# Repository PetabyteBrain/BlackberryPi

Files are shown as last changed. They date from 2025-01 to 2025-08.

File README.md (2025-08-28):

<!-- Improved compatibility of back to top link: See: https://github.com/othneildrew/Best-README-Template/pull/73 -->

<!--
*** Thanks for checking out the Best-README-Template. If you have a suggestion
*** that would make this better, please fork the repo and create a pull request
*** or simply open an issue with the tag "enhancement".
*** Don't forget to give the project a star!
*** Thanks again! Now go create something AMAZING! :D
-->

<!-- PROJECT SHIELDS -->
<!--
*** I'm using markdown "reference style" links for readability.
*** Reference links are enclosed in brackets [ ] instead of parentheses ( ).
*** See the bottom of this document for the declaration of the reference variables
*** for contributors-url, forks-url, etc. This is an optional, concise syntax you may use.
*** https://www.markdownguide.org/basic-syntax/#reference-style-links
-->
[][contributors-url]
[][forks-url]
[][stars-url]
[][issues-url]
[][license-url]
[][linkedin-url]

<!-- PROJECT LOGO -->
<br />
<div align="center">
  <a href="https://github.com/PetabyteBrain/BlackberryPi">
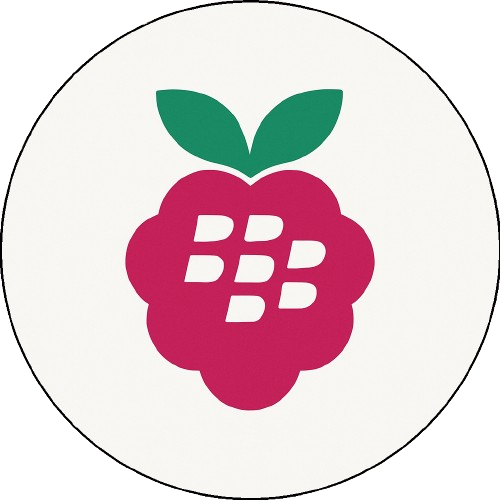
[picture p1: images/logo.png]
    
  </a>

<h3 align="center">Blackberry Pi</h3>

  <p align="center">
    The "BlackBerry Pi" project aims to transform a classic BlackBerry phone by integrating a Raspberry Pi as its core, creating a modern, customizable device with a retro design.
    <br />
    <a href="https://github.com/PetabyteBrain/BlackberryPi"><strong>Explore the docs »</strong></a>
    <br />
    <br />
    <a href="https://github.com/PetabyteBrain/BlackberryPi">View Demo</a>
    ·
    <a href="https://github.com/PetabyteBrain/BlackberryPi/issues/new?labels=bug&template=bug-report---.md">Report Bug</a>
    ·
    <a href="https://github.com/PetabyteBrain/BlackberryPi/issues/new?labels=enhancement&template=feature-request---.md">Request Feature</a>
  </p>
</div>

<!-- TABLE OF CONTENTS -->
<details>
  <summary>Table of Contents</summary>
  <ol>
    <li>
      <a href="#about-the-project">About The Project</a>
      <ul>
        <li><a href="#built-with">Built With</a></li>
      </ul>
    </li>
    <li>
      <a href="#getting-started">Getting Started</a>
      <ul>
        <li><a href="#prerequisites">Prerequisites</a></li>
        <li><a href="#installation">Installation</a></li>
        <li><a href="#additional-stuff">Additional stuff</a></li>
      </ul>
    </li>
    <li><a href="#build-example">Build example</a></li>
    <li><a href="#roadmap">Roadmap</a></li>
    <li><a href="#BOM (Bill of Materials)">BOM (Bill of Materials)</a></li>
    <li><a href="#contributing">Contributing</a></li>
    <li><a href="#license">License</a></li>
    <li><a href="#contact">Contact</a></li>
    <li><a href="#acknowledgments">Acknowledgments</a></li>
    <li><a href="#scripts">Scripts</a></li>
    <li><a href="#3d-plans">3D Plans</a></li>
  </ol>
</details>

<!-- ABOUT THE PROJECT -->
## About The Project

<div align="center">
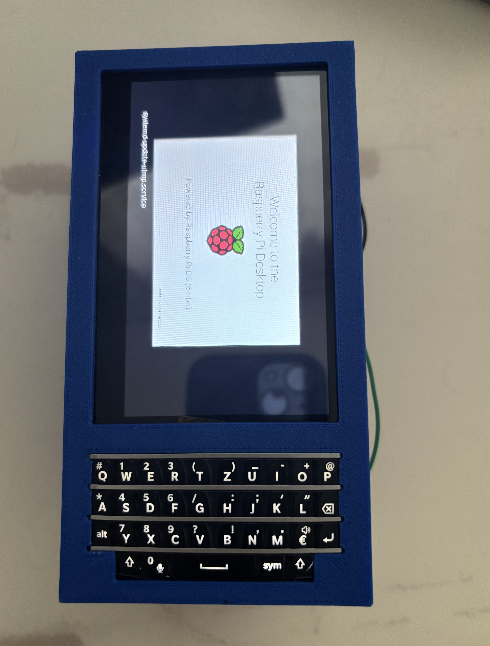
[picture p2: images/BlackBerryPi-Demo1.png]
Blackberry Pi
  
</div>

This project is all about bringing the iconic BlackBerry style back to life but with a twist. Instead of using outdated hardware, we’re giving it a modern upgrade by building it around a Raspberry Pi. The idea is to create something that feels unique and different from the sea of touchscreens we see today while keeping it open, customizable, and fun to work with. It’s a mix of nostalgia and innovation for people who want something truly their own.
This project is under development at the moment and is a working process. Updates in this repository are to be expected.

<p align="right">(<a href="#readme-top">back to top</a>)</p>

### Built With

* [][Raspberry-url]
* [][Arduino-url]

...

<p align="right">(<a href="#readme-top">back to top</a>)</p>

<!-- GETTING STARTED -->
## Getting Started

For getting a good start it is best if you buy or install the following prerequisites and installations.  Additionally for the customization it is easiest if you have access to a 3D-printer.

### Prerequisites

<div align="center">
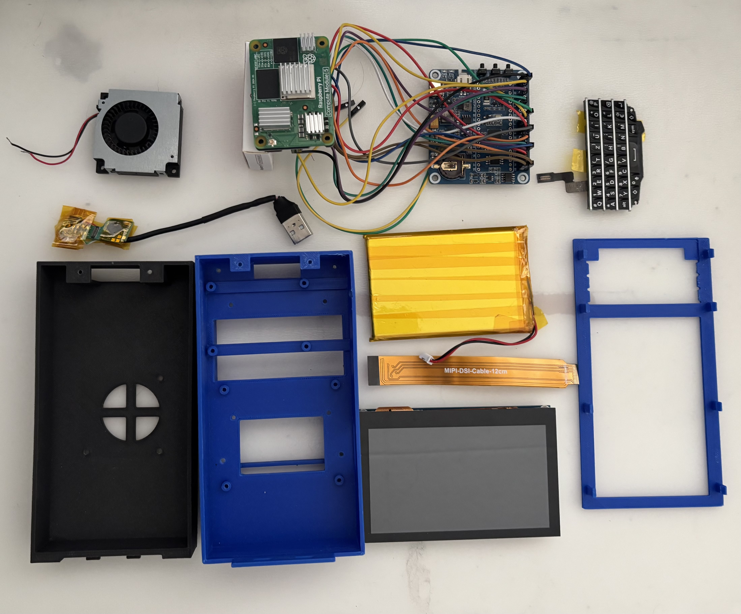
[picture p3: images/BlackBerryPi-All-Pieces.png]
Blackberry Pi
  
</div>

#### Hardware:
- Raspberry Pi Compute Module 5
- 4.3inch DSI LCD [from Waveshare]
- Nano Base Board A for CM5 [from Waveshare]
- Lipo Batterie 5000mAH 3.7V
- Power Management Hat (B) [from Waveshare]
- Keyboard from an old Blackberry Phone [from e.g. Ricardo]
- DC Brushless Fan DC12V - 0.18A Model: JD4512M12 [from e.g. eBay or a 3D-printer]

#### Software:
- On the Power Management Hat and on the Keyboard, flash these <a href="#scripts">scripts</a> for correct functionality.

### Installation:

- Raspberry Pi Imager
- Raspberry Pi boot Mass Storage Gadget

### Additional elements:
- Keyboard to display: USB cable with a type A port, the open cable should be connected to the Keyboard directly.
- Extension Cable: We integrated a makeshift female to male USB-C cable so that we can alter the placement of the UBS-C port on our phone.
- Fan to Power Managment Hat: because the fan did not have the same type of port we used jumper wires.

<p align="right">(<a href="#readme-top">back to top</a>)</p>

<!-- BUILD EXAMPLES -->
## Build Example

...

For detailed assembly instructions, see the [Assembly Guide](docs/assembly/Assembly_Guide.md).

<div align="center">
  Blackberry Pi
</div>

<p align="right">(<a href="#readme-top">back to top</a>)</p>

<!-- ROADMAP -->
## Roadmap

- [X] Create concept & research
- [X] plan prototype
- [X] build 1st Prototype
    - [ ] Optimise and upgrade Prototype
    - [ ] Build V.2
- [ ] Work on a compact version (Raspberry pi zero)
- [X] Choose OS
    - [ ] Adapt OS for Device

See the [open issues](https://github.com/PetabyteBrain/BlackberryPi/issues) for a full list of proposed features (and known issues).

<p align="right">(<a href="#readme-top">back to top</a>)</p>

<!-- Bill of Materials -->
## Bill of Materials

For a detailed list of parts required to build the BlackBerry Pi, refer to our  
[BOM (Bill of Materials)](docs/bom.md).

<p align="right">(<a href="#readme-top">back to top</a>)</p>

<!-- CONTRIBUTING -->
## Contributing

We welcome contributions of any kind — whether it's code, documentation, hardware suggestions, or just cool ideas.

See our [CONTRIBUTING.md](docs/CONTRIBUTING.md) guide for full details on how to get started.

<p align="right">(<a href="#readme-top">back to top</a>)</p>

<!-- LICENSE -->
## License

This Readme file is under the MIT License and the Rest of the Project is under the GNU General Public License. See `LICENSE.txt` for more information.

### MIT License 
```
MIT License

Copyright (c) 2021 Othneil Drew

Permission is hereby granted, free of charge, to any person obtaining a copy
of this software and associated documentation files (the "Software"), to deal
in the Software without restriction, including without limitation the rights
to use, copy, modify, merge, publish, distribute, sublicense, and/or sell
copies of the Software, and to permit persons to whom the Software is
furnished to do so, subject to the following conditions:

The above copyright notice and this permission notice shall be included in all
copies or substantial portions of the Software.

THE SOFTWARE IS PROVIDED "AS IS", WITHOUT WARRANTY OF ANY KIND, EXPRESS OR
IMPLIED, INCLUDING BUT NOT LIMITED TO THE WARRANTIES OF MERCHANTABILITY,
FITNESS FOR A PARTICULAR PURPOSE AND NONINFRINGEMENT. IN NO EVENT SHALL THE
AUTHORS OR COPYRIGHT HOLDERS BE LIABLE FOR ANY CLAIM, DAMAGES OR OTHER
LIABILITY, WHETHER IN AN ACTION OF CONTRACT, TORT OR OTHERWISE, ARISING FROM,
OUT OF OR IN CONNECTION WITH THE SOFTWARE OR THE USE OR OTHER DEALINGS IN THE
SOFTWARE.
```

<p align="right">(<a href="#readme-top">back to top</a>)</p>

<!-- CONTACT -->
## Contact

Spyros Catéchis - spyroscatechis@proton.me

Naomi Bächler - naomi.baechler@protonmail.com

Aram Amir - aram.amir07@gmail.com

Nicolas Ammeter - nicolas.ammeter@hotmail.com

Project Link: [https://github.com/PetabyteBrain/BlackberryPi](https://github.com/PetabyteBrain/BlackberryPi)

<p align="right">(<a href="#readme-top">back to top</a>)</p>

<!-- ACKNOWLEDGMENTS -->
## Acknowledgments

* [Beepy raspberry pi zero](https://beepy.sqfmi.com/)
* [Blackberry Keyboard with Arduino](https://forum.arduino.cc/t/interfacing-blackberry-q10-keypad-to-arduino-and-the-oled-typewriter/342989)
* [Adapter PCB keyboard to usb-C](https://github.com/Dakkaron/Fairberry)
* [Github Readme Template](https://github.com/othneildrew/Best-README-Template)

### Sources
#### Main idea
* [Blackberry Clone mit Raspberry pi](https://www.heise.de/news/Blackberry-Clone-mit-Raspberry-Pi-9712108.html)
* [Blackberry pi](https://magpi.raspberrypi.com/articles/blackberry-pi)
* [Blackberry pi Handheld](https://hackaday.io/project/195587-blackberrypi-handheld)

#### Hardware
##### Keyboard
* [Blackberry Keyboard with Arduino](https://forum.arduino.cc/t/interfacing-blackberry-q10-keypad-to-arduino-and-the-oled-typewriter/342989)
* [Blackberry Keyboard eevblog](https://www.eevblog.com/forum/beginners/how-to-connect-to-a-very-very-challanging-blackberry-q10-keyboard-connector/msg735622/)
* [Adafruit Blog Blackberry Keyboard](https://blog.adafruit.com/2019/01/14/interfacing-a-blackberry-q10-keyboard-into-your-microcontroller-project-blackberry-arduino-microcontroller/)
* [BBQ10KBD arturo182](https://github.com/arturo182/BBQ10KBD/tree/master)
* [Blackberry tastatur mit Bluetooth/ usb c](https://github.com/wallComputer/bbq20kbd_hw)
* [Adapter PCB keyboard to usb-C](https://github.com/Dakkaron/Fairberry)
* [Update Firmware of UsbASP programmer](https://www.electronics-lab.com/project/usbasp-firmware-update-guide/)
* [Keyboard project github](https://github.com/ZitaoTech/BBQ10-USB_BLE_Keyboard)

##### Other
* [2.8 inch Display](https://www.waveshare.com/wiki/2.8inch_DPI_LCD)
* [Compute module 5  lite, 16gb ram, wifi](https://www.welectron.com/Raspberry-Pi-Compute-Module-CM5116000-Lite-16-GB-RAM-WiFi)
* [Nano Base Board (A)](https://www.berrybase.ch/nano-base-board-a-fuer-raspberry-pi-compute-module-4?c=2410)

#### Software / OS
##### AOSP
* [Android Open Source Project (AOSP)](https://source.android.com/)
* [AOSP adapted for Raspberry pi](https://konstakang.com/devices/rpi5/)
* [Raspberry pi Vanilla](https://github.com/raspberry-vanilla)
* [Android install instructions](https://www.xda-developers.com/how-to-install-android-on-a-raspberry-pi/)

##### Other OS
* [Lineage OS](https://lineageos.org/)
* [Sailfish OS](https://sailfishos.org/)
* [Plasma mobile](https://plasma-mobile.org/)
* [Mobian](https://mobian-project.org/)
* [Manjaro](https://manjaro.org/products/download/arm)
* [Postmarket OS](https://postmarketos.org/)

#### Extra / Other
* [Pi Zero 2w + blackberry case + e-ink](https://www.reddit.com/r/RASPBERRY_PI_PROJECTS/comments/1ddj94n/pi_zero_2w_blackberry_case_eink_would_this_work/)

<p align="right">(<a href="#readme-top">back to top</a>)</p>

<!-- SCRIPTS -->
## Scripts:
### Script for Power Management Hat
In [this Link](https://www.waveshare.com/wiki/Power_Management_HAT_(B)) there are all scripts listed, that are needed to make the Power Management Hat work. There are also instructions on the use of them.

### Script for Keyboard
With [this link](https://github.com/Dakkaron/Fairberry) you will find the repo and the scripts for the binding of the input on the Keyboard to the display. Instructions can be found under that Repo.

<p align="right">(<a href="#readme-top">back to top</a>)</p>

<!-- 3D PLANS -->
## 3D Plans:

The 3d Model is made out of 3 parts and can be printed and assembled at Home.

[Here](docs/models) is a Link to the more detailed view of the model and it's construction / assembly.

<p align="right">(<a href="#readme-top">back to top</a>)</p>

<!-- MARKDOWN LINKS & IMAGES -->
<!-- https://www.markdownguide.org/basic-syntax/#reference-style-links -->
[contributors-shield]: https://img.shields.io/github/contributors/PetabyteBrain/BlackberryPi.svg?style=for-the-badge
[contributors-url]: https://github.com/PetabyteBrain/BlackberryPi/graphs/contributors
[forks-shield]: https://img.shields.io/github/forks/PetabyteBrain/BlackberryPi.svg?style=for-the-badge
[forks-url]: https://github.com/PetabyteBrain/BlackberryPi/network/members
[stars-shield]: https://img.shields.io/github/stars/PetabyteBrain/BlackberryPi.svg?style=for-the-badge
[stars-url]: https://github.com/PetabyteBrain/BlackberryPi/stargazers
[issues-shield]: https://img.shields.io/github/issues/PetabyteBrain/BlackberryPi.svg?style=for-the-badge
[issues-url]: https://github.com/PetabyteBrain/BlackberryPi/issues
[license-shield]: https://img.shields.io/github/license/PetabyteBrain/BlackberryPi.svg?style=for-the-badge
[license-url]: https://github.com/PetabyteBrain/BlackberryPi/blob/master/LICENSE.txt
[linkedin-shield]: https://img.shields.io/badge/-LinkedIn-black.svg?style=for-the-badge&logo=linkedin&colorB=555
[linkedin-url]: https://www.linkedin.com/in/spyros-catechis/
[product-screenshot]: images/screenshot.png
[Raspberry.js]: https://img.shields.io/badge/Raspberry%20Pi-A22846?style=for-the-badge&logo=Raspberry%20Pi&logoColor=white
[Raspberry-url]: https://www.raspberrypi.com/
[Arduino.js]: https://img.shields.io/badge/Arduino-00979D?style=for-the-badge&logo=Arduino&logoColor=white
[Arduino-url]: https://www.arduino.cc/
[Vue.js]: https://img.shields.io/badge/Vue.js-35495E?style=for-the-badge&logo=vuedotjs&logoColor=4FC08D
[Vue-url]: https://vuejs.org/
[Angular.io]: https://img.shields.io/badge/Angular-DD0031?style=for-the-badge&logo=angular&logoColor=white
[Angular-url]: https://angular.io/
[Svelte.dev]: https://img.shields.io/badge/Svelte-4A4A55?style=for-the-badge&logo=svelte&logoColor=FF3E00
[Svelte-url]: https://svelte.dev/
[Laravel.com]: https://img.shields.io/badge/Laravel-FF2D20?style=for-the-badge&logo=laravel&logoColor=white
[Laravel-url]: https://laravel.com

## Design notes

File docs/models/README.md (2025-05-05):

# 3d Model

The **BlackBerry Pi** case consists of **three separate** pieces that were meticulously designed using [Onshape](https://www.onshape.com/en/), a powerful cloud-based CAD platform. These components are optimized for 3D printing and tailored to accommodate the internal electronics of the project.

## Components

- **Front Panel**
Designed to frame the screen and keyboard area, this piece includes cutouts for the display and user input interface, preserving the classic BlackBerry look while integrating modern hardware.

- **Main Piece**
This is the central enclosure that houses the Raspberry Pi and other electronics. It features internal mounts and guides for secure placement of the components, ensuring structural integrity and easy assembly.

- **Back Panel**
Serves as the rear cover, with potential cutouts or vents for cooling. It snaps or screws into the main piece and can be removed for maintenance or upgrades.

## Printing & Assembly Notes

- All pieces are intended for **FDM 3D printing** and are designed with tolerances suitable for standard PLA filament.

- You may need to **add supports** for certain overhangs, especially in the main housing section.

- Consider using **M2.5 or M3 screws** if mechanical fasteners are desired.

- Total print time and filament usage will depend on your specific slicer settings and printer.

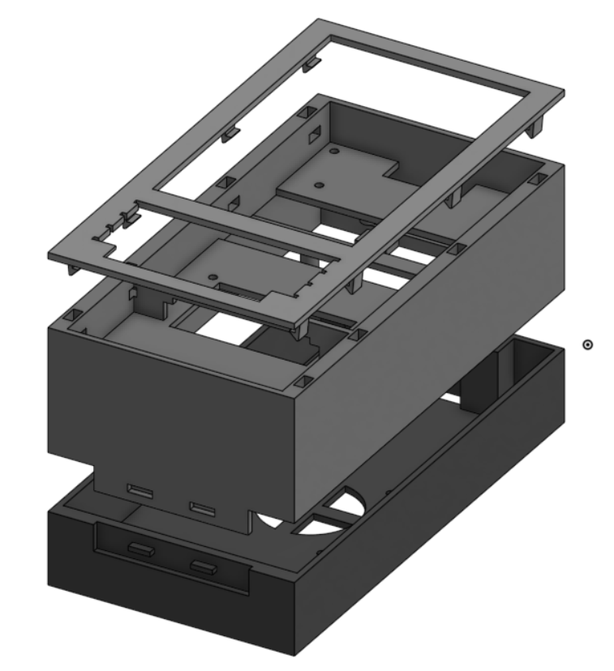
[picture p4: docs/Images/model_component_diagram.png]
diagram of model


## License

These 3D model files are distributed under the terms of the **GNU General Public License v3.0 (GPLv3)**.
This means you are free to **use, study, modify, and distribute** the models, as long as any derivative works also remain open and licensed under the same GPLv3 terms.
For more information, see the [License page](../../LICENSE) in this repository.

> ⚠️ **Note:** As the project evolves, the 3D models may be subject to change. Check this repository regularly for updated versions or design improvements.

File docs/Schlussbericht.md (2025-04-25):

Schlussbericht

|  |  |
| --- | --- |
| **Status** | **In Arbeit** / In Prüfung / Abgeschlossen |
| **Projektname** | Blackberry Pi |
| **Projektleiter** | Spyros Catéchis |
| **Auftraggeber** | Kurt Järmann |
| **Autoren** | Aram A., Nicolas A., Naomi B., Spyros C. |
| **Verteiler** | Kurt Järmann |

**Änderungskontrolle, Prüfung, Genehmigung**

|  |  |  |  |
| --- | --- | --- | --- |
| Version | Datum | Beschreibung, Bemerkung | Name oder Rolle |
| 1.0 | 25.04.2025 | Erstes befüllen | Naomi, Aram |
| 1.1 | 25.04.2025 | Raffinierung & ergänzende Infos | Naomi, Aram |
| 1.2 | 25.04.2025 | Prüfung | Spyros, Aram |
| 1.3 | 25.04.2025 | Überarbeitung | Nicolas, Aram |
| 2.0 | 25.04.2025 | Finale Abgabe | Spyros, Aram |

**Definitionen und Abkürzungen**

|  |  |
| --- | --- |
| Begriff / Abkürzung | Bedeutung |
|  |  |

**Referenzen**

|  |  |
| --- | --- |
| Referenz | Titel, Quelle |
| Projektreferenzen | GitHub Repository | [GitHub](https://github.com/PetabyteBrain/BlackberryPi) |

Inhalt

[Teil 1 4](#_Toc196486154)

[Management Abstract 4](#_Toc196486155)

[Aufgabenstellung 5](#_Toc196486156)

[1. Ausgangslage 5](#_Toc196486157)

[2. Projektziele 5](#_Toc196486158)

[3. Rahmenbedingungen 5](#_Toc196486159)

[4. Aufwand & Ressourcen 5](#_Toc196486160)

[5. Kostenübersicht (geschätzt) 5](#_Toc196486161)

[6. Kommunikation 6](#_Toc196486162)

[Deklaration 6](#_Toc196486163)

[1. Zu den vorkenntnissen 6](#_Toc196486164)

[2. Zu Vorarbeiten 7](#_Toc196486165)

[3. Zu Firmenstandards 7](#_Toc196486166)

[Zeitplan 7](#_Toc196486167)

[Arbeitsprotokoll 8](#_Toc196486168)

[Spyros 8](#_Toc196486169)

[Aram 9](#_Toc196486170)

[Naomi 10](#_Toc196486171)

[Nicolas 11](#_Toc196486172)

[Teil 2: 12](#_Toc196486173)

[Situationsanalyse 12](#_Toc196486174)

[Ausgangslage 12](#_Toc196486175)

[SystemZiele & Lösungsvorschläge 14](#_Toc196486176)

[Systemarchitektur 15](#_Toc196486177)

[Testkonzept & Testspezifikationen 16](#_Toc196486178)

[Testspezifikation 16](#_Toc196486179)

[Testprozedur 18](#_Toc196486180)

[Testprotokoll 19](#_Toc196486181)

[Benutzerdokumentation / Anleitung 21](#_Toc196486182)

[Systemübersicht 21](#_Toc196486183)

[Anwenderfunktionalität 21](#_Toc196486184)

[Projekterfahrung 22](#_Toc196486185)

[Teil 3 22](#_Toc196486186)

[Selber erstelle Listings und Skripte 22](#_Toc196486187)

[Literaturverzeichnis 22](#_Toc196486188)

[Hardware 22](#_Toc196486189)

[Software / OS 23](#_Toc196486190)

[Glossar 24](#_Toc196486191)

# Teil 1

## Management Abstract

Alles startete bei dem Ausflug ins Technikmuseum in Solothurn, dort wurde unser PO(Spyros) inspiriert, ein eigenes Blackberry-Telefon zu kreieren, einfach eines, welches mit den Standards von heute mithalten kann.

Nach dieser initialen Idee kam die Projektwoche näher und Spyros sammelte wie verrückt Quellen und konkretere Ideen. Während der Woche wurde unser Projekt mithilfe des Projektantrags und der Studie zum Leben erweckt. Nach dem November arbeiteten wir drei regelmässig an der Entwicklung unseres Telefons. Am 28. Februar stiess dann Nicolas zu unserem Projekt hinzu. Wir haben dann fleissig bis am Dienstag das Projekt fertig gemacht. Hier ist anzumerken, dass wir bis dahin noch kein Gehäuse gedruckt hatten.

Uns ist es sehr wichtig, ein gutes Open-Source-Produkt zu kreieren, somit haben wir darauf geachtet, dass das Telefon nicht lizenzierte Komponenten hat und für die meisten einfach zugänglich ist. Zudem waren die Hauptziele, dass das Telefon ein Touchdisplay hat, eine Tastatur, simple Startknöpfe, auf einem Raspberry Pi läuft und eine Batterie als Stromversorgung hat.

Dank unserer harten Arbeit haben wir gute Resultate erhalten. Wir haben ein funktionierendes Blackberry Pi Telefon, welches Sachen wie Discord oder WhatsApp-Web darauf laden kann oder sogar Spiele. Zudem haben wir eine Interne und externe Tastatur, obwohl die Interne per Default abgeschaltet ist. Das ganze Telefon hat eine LIPO Batterie, somit kann man dies gut ohne direkte Stromversorgung brauchen.

Natürlich kann ich hier nur für mich sprechen, jedoch würde ich sagen, es ist eine sehr lehrreiche Projektarbeit gewesen. Das gesamte Wissen in unserem Team über GPIO-Pins und dergleichen ist zumindest ein bisschen gestiegen. Persönlich habe ich sehr viel gelernt. Für das ganze Team war es auch eine gute Erfahrung und Übung für unsere IDPA und IPA, da diese ähnlich ablaufen werden.

## Aufgabenstellung

### 1. Ausgangslage

**Projektidee:** Ein ausgedientes BlackBerry-Smartphone wird mit einem Raspberry Pi und modernen Komponenten neu aufgebaut. Ziel ist ein Retro-Gerät mit aktuellem Funktionsumfang.
**Problem:** Physische Tastaturen verschwinden, Geräte werden grösser – dieses Projekt bietet eine kompakte Alternative für Liebhaber klassischer Eingabemethoden.
**Stand:** Erste Konzepte und technische Machbarkeitsstudien sind abgeschlossen.

### 2. Projektziele

* Einbau eines Raspberry Pi in ein BlackBerry-Gehäuse
* Funktionsfähige Hardware-Schnittstellen (Tastatur, Display)
* Erstellung eines Prototyps
* Entwicklung eines eigenen Betriebssystems (AOSP-basiert)

### 3. Rahmenbedingungen

* **Zeit:** Initialisierung bis 29.11.2024
* **Organisation:** Unterstützung durch Lehrkräfte, Online-Ressourcen
* **Methodik:** Hermes
* **Genehmigung & Planung:** durch Autoren

### 4. Aufwand & Ressourcen

**Aufwand:** ~70 Stunden für Planung, Bau, Test
**Technik:** Raspberry Pi, Display, Akku, Tastatur, Gehäuse
**Werkzeuge:** CAD-Software, Lötstation, 3D-Drucker
**Support:** Online-Recherche, Lehrkraft

### 5. Kostenübersicht (geschätzt)

| **Komponente** | **CHF** |
| --- | --- |
| Gehäuse & Tastatur | 29.60 |
| Touchscreen | 14.00 |
| PCB (via Onboard gratis) | 0.00 |
| Tastatur-Connector | 24.29 |
| Raspberry Pi | 20–80 |
| **Gesamt** | 87.89–147.89 |

### 6. Kommunikation

* Projektabstimmungen im Team & mit Auftraggeber
* Regelmässige Kurzprotokolle und Updates über Teams
* Zusammenfassungen für den Auftraggeber

**7. Risiken & Massnahmen**

| **Risiko** | **Eintritt** | **Auswirkung** | **Massnahme** |
| --- | --- | --- | --- |
| Unklare Aufgabenverteilung | Mittel | Mittel | Klare Kommunikation, tägliche Updates |
| Fehlender Zugang zu Infrastruktur | Gering | Hoch | Nutzung privater Räume, IT-Frühwarnung |
| Abstimmungsprobleme mit Auftraggeber | Mittel | Hoch | Regelmässige Rückmeldungen, direkte Kommunikation |
| Zeitliche Engpässe im Team | Mittel | Mittel | Frühzeitige Planung, Priorisierung |

## Deklaration

### 1. Zu den vorkenntnissen

Da wir vor allem mit Hardware-komponenten arbeiteten, mussten die einzigen Vorkenntnisse sein, wie man lötet, Kabel aufschneidet (Lötvorbereitung), wie GPIO-pins funktionieren. Zudem hatten drei Person Erfahrungen mit Raspberry Pi und eine davon viel Erfahrung mit Arduino. Das ganze Team hatte schon vorher ein ähnliches Projekt, ein GTTO-display; hier kam jedoch noch mehr programmieren vor als im Blackberry PI Projekt. Da es ein sehr simples Projekt war, brauchte und hatte niemand von uns eine Spezialisation oder ein relevantes Zertifikat.

### 2. Zu Vorarbeiten

Wir haben mit dem Projekt schon um den 20. September 2024 gestartet, dies waren ca. 4 bis 6 Stunden Arbeit bis wir dann offiziell in der Woche vom 23. – 27 November gestartet haben. In der Zeit zwischen der zu vorgenannten Woche und der Jetzigen waren wir wöchentlich mindestens 45 Minuten mit dem Projekt beschäftigt, dies beinhaltete Komponenten kaufen, planen von der Zusammensetzung, design-planung, Testing Einheiten von erfolgreichen Schritten.

### 3. Zu Firmenstandards

Wir haben mit dem Projekt schon um den 20. September 2024 gestartet, dies waren ca. 4 bis 6 Stunden Arbeit bis wir dann offiziell in der Woche vom 23. – 27 November gestartet haben. In der Zeit zwischen der zu vorgenannten Woche und der Jetzigen waren wir wöchentlich mindestens 45 Minuten mit dem Projekt beschäftigt, dies beinhaltete Komponenten kaufen, planen von der Zusammensetzung, design-planung, Testing Einheiten von erfolgreichen Schritten.

## Zeitplan

Der Zeitaufwand für das Projekt wird auf ungefähr **70 Stunden** geschätzt. Dies beinhaltet die folgenden Phasen:

* **Planung**: Recherche und Designphase, in der die Anforderungen und Spezifikationen festgelegt werden. Dazu gehört auch das Finden von geeigneten Hardware- und Softwarelösungen, die den Projektzielen entsprechen.
* **Aufbau und Implementierung**: Der praktische Teil des Projekts, bei dem die einzelnen Komponenten zusammengefügt werden. Hierzu zählen das Löten, die Verkabelung der Hardware, das Zusammenbauen des Gehäuses sowie das Installieren und Konfigurieren der Software.
* **Fehlerbehebung und Tests**: Nach der Implementierung wird eine Testphase durchgeführt, um sicherzustellen, dass alle Funktionen wie vorgesehen arbeiten. Dazu gehört das Debuggen von Softwareproblemen und die Optimierung der Hardware-Integration.

## Arbeitsprotokoll

### Spyros

Spyros war in mehrfacher Hinsicht ein wichtiger Teil des Teams. Bereits zu Beginn der Projektphase erklärte er sich bereit, die **Finanzierung** zu übernehmen. Er besorgte nicht nur die Bauteile, sondern kümmerte sich auch um die Logistik – also Bestellung, Lieferung und rechtzeitige Bereitstellung der Materialien. Diese Verantwortung übernahm er eigenständig, wodurch dem Team wertvolle Zeit für die technische Arbeit zur Verfügung stand.

Im technischen Bereich war seine grösste Leistung die Erstellung des **3D-Modells des Handy-Gehäuses**. Er nutzte hierfür spezialisierte Software und baute das Modell in enger Rücksprache mit Aram und Naomi schrittweise auf. Dabei achtete er auf eine präzise Umsetzung der vorgegebenen Masse und eine praxisnahe Anordnung der Bauteile. Sein Beitrag im Bereich der 3D-Modellierung war der umfangreichste im gesamten Team.

Auch in der **Script-Recherche** zeigte sich Spyros sehr engagiert. Er analysierte verschiedene Optionen, testete erste Umsetzungen und trug zur finalen Auswahl der Skripte bei, mit denen das Gerät betrieben wurde. In dieser Phase arbeitete er eng mit Aram zusammen, um praktikable und funktionierende Lösungen zu identifizieren.

Ein weiterer Beitrag lag in der **Mitarbeit an der logischen Planung** des Geräts. Spyros war stark darin, technische Zusammenhänge zu erfassen und Vorschläge zu machen, wie etwa Kabelverläufe optimiert oder Komponenten effizienter untergebracht werden könnten. Seine Einschätzungen waren oft sehr praxisorientiert und halfen dabei, mögliche Probleme im Aufbau frühzeitig zu erkennen.

In der **Dokumentation** brachte er sich zwar nur vereinzelt ein, lieferte aber technische Inhalte und unterstützte insbesondere Naomi bei der Formulierung technischer Abschnitte.

Spyros überzeugte durch technisches Geschick, Problemlösungsorientierung und einen hohen Grad an Eigenverantwortung, insbesondere in den Bereichen Finanzierung, 3D-Modellierung und technische Planung.

### Aram

Aram übernahm im Verlauf des Projekts eine zentrale Rolle und war in nahezu allen Bereichen aktiv eingebunden. Als Allrounder konnte er sich flexibel an die jeweiligen Anforderungen anpassen und übernahm Verantwortung für verschiedene Schlüsselaspekte der Projektarbeit.

Ein wesentlicher Teil seiner Arbeit bestand in der **Ausarbeitung der Präsentation**, mit der das Team das Projekt abschliessend vorstellte. Er kümmerte sich sowohl um den visuellen Aufbau als auch um die inhaltliche Ausformulierung der Präsentation, wobei er besonderen Wert auf Struktur, Verständlichkeit und Präzision legte.

Zusätzlich war Aram massgeblich an der **Recherche und Auswahl geeigneter Scripts** beteiligt. Diese Scripts bildeten die Grundlage für die Funktionsweise des Projekts und mussten sorgfältig analysiert, angepasst und integriert werden. Aram trug hier wesentlich dazu bei, passende Lösungen zu finden und funktionale Abläufe zu gewährleisten.

Auch die **logische Konzeption des Aufbaus des DIY-Handys** wurde in enger Abstimmung mit den anderen Teammitgliedern von ihm mitentwickelt. Aram behielt stets den Gesamtüberblick und sorgte dafür, dass alle Bauteile und Softwareelemente sinnvoll zusammenspielten.

Er engagierte sich stark beim **Löten der Hardwarekomponenten** und stellte sicher, dass die Verbindungen technisch einwandfrei und sauber ausgeführt wurden – eine wichtige Voraussetzung für die Funktionstüchtigkeit des Geräts.

Im gestalterischen Bereich übernahm er zusammen mit Spyros die Entwicklung des **3D-Modells des Handy-Gehäuses**. Aram lieferte eigene Ideen zur Form, Ergonomie und zum technischen Aufbau des Gehäuses, und arbeitete aktiv in der Modellierungsphase mit.

Auch bei der **Dokumentation** des Projekts brachte Aram sich umfassend ein. Er strukturierte die Inhalte mit und half dabei, technische Abläufe verständlich darzustellen. Insgesamt zeichnete sich Aram durch eine hohe Einsatzbereitschaft, Vielseitigkeit und Eigeninitiative aus, was für das Gelingen des Projekts wesentlich war.

### Naomi

Naomi war eine der tragenden Säulen des Projekts – sowohl im schriftlichen als auch im technischen Bereich. Ihre Hauptverantwortung lag bei der **Dokumentation**, die sie mit grosser Sorgfalt und Struktur erstellte. Sie investierte viel Zeit in die Ausformulierung der einzelnen Abschnitte, achtete auf klare Formulierungen, inhaltliche Genauigkeit sowie einheitliche Gestaltung. Besonders bei komplexen technischen Zusammenhängen verstand sie es, die Inhalte so zu formulieren, dass sie auch für Aussenstehende verständlich wurden.

Darüber hinaus war Naomi intensiv in die **logische Planung und Struktur des Aufbaus** des DIY-Handys eingebunden. Sie arbeitete eng mit Aram und Spyros zusammen und half bei der Entscheidung, wie die verschiedenen Hardware- und Software-Komponenten sinnvoll aufeinander abgestimmt werden können. Dabei zeigte sie ein gutes Verständnis für funktionale Abläufe und bewies ein gutes Gespür für die technische Umsetzung.

Auch im **3D-Modelling** war Naomi beteiligt. Obwohl der Grossteil von Spyros umgesetzt wurde, leistete sie inhaltliche Zuarbeit, brachte Verbesserungsvorschläge ein und übernahm kleinere Modellierungsaufgaben. Besonders im Bereich der Detailgestaltung – wie z.B. der Platzierung bestimmter Bauteile im Gehäuse – lieferte sie hilfreiche Inputs, die zur finalen Qualität des Modells beitrugen.

Zusätzlich war Naomi eine konstante und verlässliche Teamplayerin, die sich proaktiv einbrachte, den Überblick über wichtige Arbeitsschritte behielt und die Zusammenarbeit im Team mit ihrer strukturierten Art positiv beeinflusste. Ihr Beitrag war durchgehend bedeutend und inhaltlich vielseitig.

### Nicolas

Nicolas kam im späteren Verlauf des Projekts zum Team und fand sich rasch in die bestehende Arbeitsstruktur ein. Obwohl er nicht von Beginn an involviert war, bemühte er sich, sich konstruktiv einzubringen und übernahm gezielt Aufgaben, die das Team entlasteten. Sein Beitrag war zwar nicht so umfassend wie der der anderen Teammitglieder, dennoch war seine Unterstützung in bestimmten Bereichen hilfreich und wertvoll.

Ein Schwerpunkt seiner Tätigkeit lag im Bereich der **praktischen Umsetzung**, insbesondere beim **Löten**. In dieser technisch sensiblen Phase half er bei der Verbindung einzelner Komponenten und unterstützte dabei, dass die Hardware korrekt miteinander verschaltet wurde. Auch wenn er diese Tätigkeit nicht hauptverantwortlich übernahm, war seine Unterstützung bei der Durchführung und Vorbereitung der Lötarbeiten eine spürbare Entlastung für das Team.

Darüber hinaus beteiligte sich Nicolas auch an der **Erstellung der Projektdokumentation**. In Abstimmung mit Naomi und Aram ergänzte er bestehende Texte, überarbeitete kleinere Abschnitte und half bei der Korrektur von Formulierungen und technischen Beschreibungen. Dabei zeigte er eine sorgfältige Herangehensweise, mit dem Ziel, die Dokumentation sprachlich zu verfeinern und inhaltlich zu vervollständigen.

Nicolas war auch bei mehreren Teamtreffen präsent, wo er sich aktiv in Gespräche über technische Abläufe und gestalterische Entscheidungen einbrachte. Besonders bei der Planung kleinerer Details – etwa der Platzierung von Bauteilen oder organisatorischen Aufgaben – lieferte er hin und wieder hilfreiche Anmerkungen. Er zeigte Interesse an den technischen Prozessen und stellte Fragen, um die Zusammenhänge besser zu verstehen und gegebenenfalls mitarbeiten zu können.

Auch wenn sein Beitrag im Vergleich zu den anderen Teammitgliedern punktueller war, war seine Bereitschaft zur Mitarbeit deutlich spürbar. In den ihm übertragenen Aufgabenbereichen arbeitete er gewissenhaft und trug dazu bei, das Gesamtprojekt zu unterstützen.

Seine Rolle kann als **ergänzend und unterstützend** beschrieben werden – weniger im konzeptionellen oder gestalterischen Bereich, aber umso mehr im praktischen Mitwirken, wo er durch seine ruhige und konzentrierte Arbeitsweise half, Aufgaben effizient abzuschliessen.

# Teil 2:

## Situationsanalyse

### Ausgangslage

Die Telefone von BlackBerry waren einst die unangefochtenen Marktführer im Smartphone-Bereich und besonders beliebt bei Geschäftskunden, da sie eine physische Tastatur, hohe Sicherheit und effiziente E-Mail-Verwaltung boten. Mit der Einführung des iPhones und der Touchscreen-Revolution durch Apple verschob sich der Fokus der Nutzer jedoch weg von Tastaturen hin zu grossen, interaktiven Displays. BlackBerry verpasste es, sich schnell genug anzupassen, und verlor schliesslich seinen Platz als Marktführer.

Heute ähneln sich die meisten Smartphones in Design und Funktionalität, was die Vielfalt am Markt stark eingeschränkt hat. In dieser homogenen Welt sehen wir eine Chance, BlackBerry neu zu interpretieren und etwas Einzigartiges zu schaffen.

Die bewährte BlackBerry-Architektur und die physische Tastatur bieten weiterhin viele Vorteile, insbesondere für Nutzer, die ein Gerät mit einer "echten" Tasteneingabe bevorzugen. Durch den Einsatz eines Raspberry Pi als Kern können wir die klassische Hardware mit moderner Technik kombinieren und ein Smartphone kreieren, das sowohl funktional als auch innovativ ist. Dieses neue Gerät vereint das Beste aus zwei Welten: Die Retro-Ästhetik und Haptik eines BlackBerry mit der Flexibilität und Leistungsfähigkeit eines Raspberry Pi – und bringt endlich wieder ein „neues Format“ auf den Smartphone-Markt.

#### Stärken

* Da die meisten Handys heutzutage ähnlich aussehen, hätten wir mit der Ästhetik des Blackberrys und der Tastatur einen Vorteil, da es anders als das Produkt der Konkurrenz ist. Dieses aussehen kann einen attraktiven Verkaufspunkt für Blackberry Enthusiasten sein.
* Dazu haben wir den Vorteil, dass wir unser Produkt Open Source behalten und deswegen jeder Nutzer genau wissen kann, was es beinhaltet und was er eingeht beim Gebrauch unserer Software.
* Kosteneffiziente Hardware, Beispiel Raspberry Pi. Der Vorteil davon ist, dass die Reparaturen einfach vom Nutzer / einem Dienst gemacht werden können und günstiger wären als andere moderne Handys.
* Das Blackberry Pi kann auch mit anderen Betriebssystemen laufen, solange es mit den Drivern und Hardware kompatibel ist.
* Da es Open Source ist, kann es die Möglichkeit geben, Anpassungen am Gerät zu führen, um diese Benutzerspezifisch zu gestalten und zu entwickeln.

#### Schwächen

#### Hohe Abhängigkeit von proprietärer Software:

Viele Nutzer sind auf geschlossene OS (z.B. iOS, Android) angewiesen. Ein offenes, anpassbares System basierend auf Raspberry Pi kann die Abhängigkeit reduzieren.

#### Hohe Kosten moderner Smartphones:

Premium-Smartphones sind oft sehr teuer. Ein DIY-Handy auf Basis eines Raspberry Pi bietet eine kostengünstige Alternative, insbesondere für technikaffine Nutzer.

#### Komplizierte Reparierbarkeit:

Viele aktuelle Smartphones sind schwierig zu reparieren (z.B. durch verklebte Komponenten). Unser Projekt kann durch ein modulares Design mit leicht austauschbaren Teilen punkten.

#### Mangelnde Software-Upgrades bei älteren Geräten:

Hersteller unterstützen ältere Modelle oft nicht mehr mit Updates, was Sicherheitsrisiken birgt. Ein offenes System erlaubt langfristige Pflege und Updates durch die Community.

#### Eingeschränkte Anpassbarkeit:

Nutzer können Design, Funktionen und Hardware ihrer Smartphones nur begrenzt anpassen. Mit einem Raspberry Pi sind massgeschneiderte Anpassungen möglich.

## SystemZiele & Lösungsvorschläge

#### Freie OS Wahl:

Mit einer freien resp. unabhängigen OS Wahl ist die Bandbreite des Blackberrys viel besser und man kann.

#### Kosten & Marken:

Solange man nicht nur für die Marke bezahlt ist ein Smartphone schon sehr viel billiger, wenn wir dies mit simpler Technologie verknüpfen, bekommen wir ein einfaches Telefon und faires Preis-Leistung Verhältnis.

#### Simple Technologie:

Da wir unser Blackberry Pi mit einem Raspberry Pi ausstatten, ein Screen und noch eine Tastatur hinzufügen ist das ganze Telefon sehr simpel und wenn ein Natel simpel ist, ist es auch simpel zum Reparieren. Was vor allem für ein kostengünstiges design ein Schlüsselziel ist.

#### Sicherstellung langfristiger Software-Upgrades durch ein offenes System:

Das Projekt BlackBerry Pi zielt darauf ab, ein Smartphone mit einem offenen Betriebssystem zu entwickeln, das von der Community unterstützt werden kann. Dadurch wird es Nutzern ermöglicht, regelmässig Sicherheitsupdates und neue Funktionen zu erhalten, unabhängig von der Herstellerunterstützung. Dies reduziert Sicherheitsrisiken und verlängert die Nutzungsdauer des Geräts erheblich.

#### Personalisierung:

Durch die simple Technologie und die freie OS-wahl ist das Natel individualisierbar. Das heisst der Nutzer kann alles personalisieren, eigene teile zum Telefon zusammenstellen. Wenn der Nutzer sehr viel Technik wissen hat, könnte er sogar zuhause sein Handy personalisieren.

## Systemarchitektur

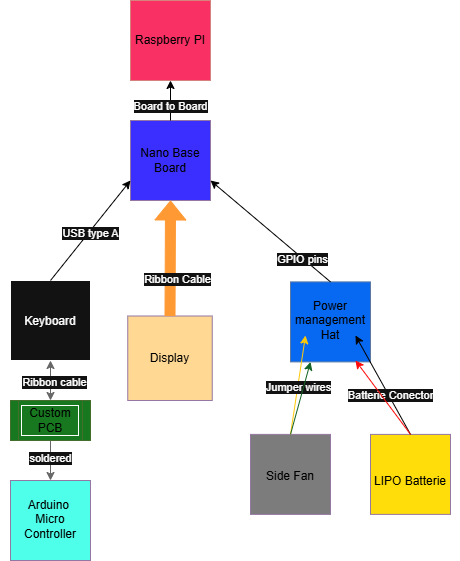
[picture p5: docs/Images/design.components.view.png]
Design Components View


## Testkonzept & Testspezifikationen

### Testspezifikation

#### Kritikalität der Funktionseinheit

|  |  |  |
| --- | --- | --- |
| **Funktionseinheit** | **Kritikalität** | **Begründung** |
| Recheneinheit (Raspberry Pi) | Hoch | Ohne funktionierende Recheneinheit ist keine Systemfunktion möglich. |
| Stromversorgung (Akku) | Hoch | Das System ist ohne Stromversorgung nicht betriebsbereit. |
| Betriebssystem / Root-Zugriff | Hoch | Notwendig für alle weiteren Software-Tests und Anpassungen. |
| Tastatur (Hardware-Eingabe) | Mittel | Grundlegende Eingabe notwendig, jedoch durch Bildschirm ggf. ergänzbar. |
| WLAN | Mittel | Essentiell für viele Anwendungen, aber Systemstart auch offline möglich. |
| Gehäuse (3D-Druck) | Niedrig | Physisch wichtig, aber nicht kritisch für Softwarefunktionen. |

#### Testanforderungen

Tests mit Normal-, Grenz- und Fehlerwerten.

Tests unter Ausnahmebedingungen (z. B. Akkuwechsel im Betrieb).

Alle Testergebnisse werden protokolliert.

#### Testverfahren

Vorbereitung:

Komponenten anschliessen, OS installieren, Stromversorgung sichern.

Durchführung:

Durchführung gemäss Testfalltabellen, manuell.

Auswertung:

Vergleich von Ist- mit Sollverhalten, Bewertung als „Bestanden / Nicht bestanden“.

#### Testkriterien

Abdeckungsgrad: Mindestens ein Test pro Anforderung.

Checklisten: Alle Modul- und Systemfunktionen abgedeckt.

Ende-Kriterien: Keine Fehler in hochkritischen Modulen, System vollständig funktionsfähig.

#### Testfälle

|  |  |  |  |  |  |  |
| --- | --- | --- | --- | --- | --- | --- |
| **Nr.** | **AFo-Nr.** | **Anwendungsfall**  **(ggf. orientiert an Use Cases)** | **Ausgangssituation** | **Eingabedaten** | **erwartetes Ergebnis** | **Bemerkungen, Prüfergebnis** |
| T1 | A5 | Akku ausstecken | Gerät ist ausgeschaltet | Akku entfernen und wieder einsetzen | Gerät startet wie erwartet | Es funktioniert wie erwartet |
| T2 | A6 | Gehäuse prüfen (3D-Druck) | Gehäuseteile vorhanden | Zusammenbauen | Teile passen genau, Gerät sitzt fest |  |
| T3 | A7 | WLAN-Verbindung testen | WLAN verfügbar | SSID + Passwort eingeben | Verbindung bleibt stabil | Wlan lässt sich verbinden und es bleibt verbunden |
| T4 | A2 | Tastatureingabe testen | System betriebsbereit | Text eingeben | Zeichen werden korrekt dargestellt | Tastatur funktioniert |
| T5 | A8 | Konfigurationsdatei ändern | config.yaml geladen | Parameter ändern | Änderung zeigt Auswirkungen im Verhalten | Dies funktioniert |
| T6 | A9 | Budgetprüfung | Komponentenliste vorhanden | Preise eintragen | Gesamtkosten ≤ 250 € |  |
| T7 | A10 | Nachbau mit Doku | Nur Dokumentation vorhanden | Gerät nach Anleitung bauen | Gerät funktioniert wie geplant |  |

### Testprozedur

#### Vorbereitung

OS-Installation auf SD-Karte abgeschlossen

Alle Module verbunden (ohne Kamera & Audio)

WLAN-SSID & Passwort bekannt

Voraussetzungen:
Alle Komponenten liegen vor und sind überprüft.

Tools zur Durchführung sind verfügbar.

Dokumentation für Referenztests ist vollständig und zugänglich.

Konfiguration:
Raspberry Pi in 3D-gedrucktem Gehäuse eingebaut.

Display, Tastatur und Akku korrekt verbunden.

Alle verwendeten Konfigurationsdateien befinden sich auf dem System.

Testumgebung: stabile Stromversorgung, lokales Netzwerk, stabile Tischunterlage für Gehäusetests.

#### Durchführung

Initialisierung: System einschalten oder vorbereiten (z. B. Komponenten einsetzen).

Durchführung: Entsprechend des Testfalls Eingaben tätigen, Komponenten prüfen, Funktionen aufrufen oder physikalische Veränderungen vornehmen.

Beobachtung: Reaktion des Systems oder Moduls beobachten.

Vergleich: Ergebnis mit dem erwarteten Resultat aus der Testspezifikation vergleichen.

Dokumentation: Testausgang (Erfolg, Fehler, Besonderheiten) direkt erfassen.

#### Nachbearbeitung

Auswertung der Resultate:

Das Ergebnis wird direkt nach jedem Testschritt dokumentiert (z. B. Tabelle oder digitales Protokoll).

Wenn nötig, werden Screenshots, Fotos oder Log-Dateien als Beleg gesichert.

Fehlermeldungen:

Auffälligkeiten (z. B. keine Reaktion, Bootfehler) werden mit Uhrzeit und Beschreibung festgehalten.

Bei Abweichung vom Soll: Testwiederholung und Prüfung der Fehlerquelle.

Protokollierung:

Ergebnisse werden in der Testprotokoll-Tabelle eingetragen (siehe 4.3.2).

Jede Abweichung wird auch im Abschnitt Testauswertung (4.3.3) kommentiert.

### Testprotokoll

#### Testobjekt

Testobjekt: Raspberry-Pi-basiertes System mit modularer Bauweise (Version: v1.0)

Testfall: T1 – Akku entfernen und wieder einsetzen

Tester: Nicolas Ammeter

Ort: Innovationlab

Datum: 23.04.2025

Uhrzeit: 14:10 – 14:15 Uhr

#### Testresultate

|  |  |  |  |
| --- | --- | --- | --- |
| **Zeitpunkt** | **Handlung** | **Beobachtung** | **Bewertung** |
| 14:10 Uhr | System ist ausgeschaltet | Keine Aktivität sichtbar | Erwartungsgemäss |
| 14:11 Uhr | Akku entnommen | Kein Widerstand, Stecker gut gelöst | Erwartungsgemäss |
| 14:12 Uhr | Akku wieder eingesetzt | Verbindung sitzt fest | Erwartungsgemäss |
| 14:13 Uhr | Gerät eingeschaltet (Power-Button) | LED leuchtet, System startet korrekt | **Bestanden** |

Erwartetes Ergebnis laut Spezifikation: Gerät startet nach Akkueinbau fehlerfrei → erfüllt

Zwischenergebnisse: Keine Zwischenstörungen, keine Verzögerung beim Boot

#### Testauswertung

Abweichungen zur Spezifikation: Keine

Einfluss auf Funktionalität: Keine Einschränkung festgestellt. System funktioniert einwandfrei nach Akku-Wiedereinbau.

Mögliche Fehlerursachen: Keine aufgetreten

Trendbeobachtung: Keine Häufung ähnlicher Fehler – Test zeigt, dass die modulare Stromversorgung zuverlässig funktioniert.

## Benutzerdokumentation / Anleitung

### Systemübersicht

Unser Hauptziel ist es, ein portables, austauschbares, open source Telefon zu kreieren. Unser Telefon basiert auf einem Raspberry Pi, welches in ein Blackberry integriert wird. Die einzige externe Schnittstelle ist ein USB-Type-C-Kabel-Port, dieser wird gebraucht, um das Telefon aufzuladen. Da wir nicht mit Daten und sonstigen Informationen arbeiten, haben wir weder verschiedene Nutzer noch Schutzmassnahmen implementiert. Da unser Projekt open source ist, ist es in der Verantwortung jeden Users, sich selbst zu schützen.

### Anwenderfunktionalität

Das Telefon ist ein recht simples Ding, es kann sich jedoch mit dem Internet verbinden, hat einen Touchscreen und hat trotzdem eine echte Tastatur. Um das Telefon zu benutzen, muss man es nur zusammensetzen, es aufladen, danach kann man es schon versklaven. Damit wir das alles testen können, ist die simpelste Aufgabe, ein Wortspiel im Browser zu öffnen und dies danach zuspielen. Somit sollte man in den Browser kommen, das Spiel mittels der Tastatur spielen und das alles ohne Probleme. Um das Telefon abzuschalten, muss man ins Menu gehen und dort auf Shutdown klicken. Um es danach wieder zu starten, muss man nur auf den Button am Case drücken und es schaltet sich ein. Wir haben keine Software verbundenen Fehlermeldungen, die nicht von Raspberry Pi kommen, und für diese gibt es ein eigenes [Handbuch](https://www.raspberrypi.com/documentation/). Somit gibt es nicht wirkliche Software-Recovery-Plans von unserer Seite, für die Hardware-Recovery kann man das Supporthandbuch, Kapitel 3.3.2, konsultieren.

## Projekterfahrung

Wir haben schlussendlich alle unsere Grundziele erreicht. Wir haben ein funktionierendes Blackberry-Phone, welches auf der Basis eines Raspberry Pis läuft, mit einem Touchscreen, einer Tastatur und Buttons, um das Telefon zu bedienen. Unser Design war nicht wirklich ein Grundziel, jedoch war es ein sehr wichtiger Bestandteil unseres Projekts.

Für unsere Gruppe war dieses Projekt eine Bereicherung an Praxisbezug in unserem Feld. Die Teamarbeit war gut und die Kommunikation lief immer sehr offen. Zeitprobleme hatten wir nie. Die einzige Verspätung war wegen eines Drucks und wir haben es schnell wieder aufgearbeitet.

Nächstes mal probieren wir, schon früher mit dem 3D-drucken zu starten, einfach damit wir nie in Zeitdruck geraten.

Die Zukunft für dieses Projekt sieht gut aus, denn wir haben noch etwa 4 Weiterentwicklungsmöglichkeiten gefunden. Diese wären: Display-Orientierungserkennung, eine SIM-Karten-Integration, damit es zu einem wahrhaftigen Telefon wird, weitere externe Ports und eine Kameraanbindung.

Somit ist unser Telefon zwar kommunikations- und funktionsfähig, jedoch hat es noch viel Verbesserungspotenzial, welches diese Gruppe in Zukunft angehen will.

# Teil 3

## Selber erstelle Listings und Skripte

Die sind alle im Github aufzufinden.

## Literaturverzeichnis

### Hardware

#### Keyboard

* [Blackberry Keyboard with Arduino](https://forum.arduino.cc/t/interfacing-blackberry-q10-keypad-to-arduino-and-the-oled-typewriter/342989)
* [Blackberry Keyboard eevblog](https://www.eevblog.com/forum/beginners/how-to-connect-to-a-very-very-challanging-blackberry-q10-keyboard-connector/msg735622/)
* [Adafruit Blog Blackberry Keyboard](https://blog.adafruit.com/2019/01/14/interfacing-a-blackberry-q10-keyboard-into-your-microcontroller-project-blackberry-arduino-microcontroller/)
* [BBQ10KBD arturo182](https://github.com/arturo182/BBQ10KBD/tree/master)
* [Blackberry tastatur mit Bluetooth/ usb c](https://github.com/wallComputer/bbq20kbd_hw)
* [Adapter PCB keyboard to usb-C](https://github.com/Dakkaron/Fairberry)
* [Update Firmware of UsbASP programmer](https://www.electronics-lab.com/project/usbasp-firmware-update-guide/)
* [Keyboard project github](https://github.com/ZitaoTech/BBQ10-USB_BLE_Keyboard)

#### Other

* [2.8 inch Display](https://www.waveshare.com/wiki/2.8inch_DPI_LCD)
* [Compute module 5 lite, 16gb ram, wifi](https://www.welectron.com/Raspberry-Pi-Compute-Module-CM5116000-Lite-16-GB-RAM-WiFi)
* [Nano Base Board (A)](https://www.berrybase.ch/nano-base-board-a-fuer-raspberry-pi-compute-module-4?c=2410)

### Software / OS

#### AOSP

* [Android Open Source Project (AOSP)](https://source.android.com/)
* [AOSP adapted for Raspberry pi](https://konstakang.com/devices/rpi5/)
* [Raspberry pi Vanilla](https://github.com/raspberry-vanilla)
* [Android install instructions](https://www.xda-developers.com/how-to-install-android-on-a-raspberry-pi/)

#### Other OS

* [Lineage OS](https://lineageos.org/)
* [Sailfish OS](https://sailfishos.org/)
* [Plasma mobile](https://plasma-mobile.org/)
* [Mobian](https://mobian-project.org/)
* [Manjaro](https://manjaro.org/products/download/arm)
* [Postmarket OS](https://postmarketos.org/)

#### Extra / Other

* [Pi Zero 2w + blackberry case + e-ink](https://www.reddit.com/r/RASPBERRY_PI_PROJECTS/comments/1ddj94n/pi_zero_2w_blackberry_case_eink_would_this_work/)

## Glossar

|  |  |
| --- | --- |
| Begriff | Erklärung |
|  |  |
| Blackberry | Eine alte Telefonmarke, die lange Marktführer war vor Apple |
| Raspberry Pi | Ein mini Computer Apparat ist, welches selbst ansteuerbar ist |
| 3D-Druck | Ein Model das durch Filament und ein spezieller Drucker erstellt wird |
| Scripts | Code Dateien welche z.B.: der Tastatur sagt, wie sie ansteuerbar ist |
| GPIO | **G**eneral-**p**urpose **I**nput / **O**utput 🡪Schnittstelle von Base Boards u. ä. |
| LIPO | **L**ithium **p**olymer Batterie |

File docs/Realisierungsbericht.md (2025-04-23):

# Realisierungsbericht

| **Status** | In Arbeit / In Prüfung / **Abgeschlossen** |
| --- | --- |
| **Projektname** | Blackberry Pi |
| **Projektleiter** | Spyros Catéchis |
| **Auftraggeber** | Kurt Järmann |
| **Autoren** | Aram A., Nicolas A., Naomi B., Spyros C. |
| **Verteiler** | Kurt Järmann |

**Änderungskontrolle, Prüfung, Genehmigung**

|  |  |  |  |
| --- | --- | --- | --- |
| Version | Datum | Beschreibung, Bemerkung | Name oder Rolle |
| 1.0 | 22.04.2025 | Erstes befüllen | Naomi, Nicolas |
| 1.1 | 23.04.2025 | Raffinierung & ergänzende Infos | Naomi, Nicolas | Aram |
| 1.2 | 23.04.2025 | Prüfung | Spyros |
| 1.3 | 23.04.2025 | Überarbeitung | Naomi |
| 2.0 | 23.04.2025 | Finale Abgabe | Spyros |

**Definitionen und Abkürzungen**

|  |  |
| --- | --- |
| Begriff / Abkürzung | Bedeutung |
| PMH | Power Management Hat |
| A Female | USB type A Female port |

**Referenzen**

|  |  |
| --- | --- |
| Referenz | Titel, Quelle |
| Projektreferenzen | GitHub Repository | [GitHub](https://github.com/PetabyteBrain/BlackberryPi) |

**Inhaltsverzeichnis**

[1 Zusammenfassung 3](#_Toc196311217)

[2 Technische Detailspezifikation 3](#_Toc196311218)

[2.1 Systemdesign 3](#_Toc196311219)

[2.1.1 Struktur 3](#_Toc196311220)

[2.1.2 Beschreibung der Elemente 3](#_Toc196311221)

[2.2 Schnittstellendefinitionen 4](#_Toc196311222)

[2.3 Sicherheit (ISDS) 4](#_Toc196311223)

[2.4 Anforderungszuordnung 4](#_Toc196311224)

[3 Systemdokumentation 4](#_Toc196311225)

[3.1 Konfigurations-Dokumentation 4](#_Toc196311226)

[3.2 Benutzerhandbuch 5](#_Toc196311227)

[3.2.1 Systemübersicht 5](#_Toc196311228)

[3.2.2 Anwenderfunktionalität 5](#_Toc196311229)

[3.3 Supporthandbuch 5](#_Toc196311230)

[3.3.1 Massnahmen bei Benutzerproblemen 5](#_Toc196311231)

[3.3.2 Massnahmen bei technischen Problemen 5](#_Toc196311232)

[3.3.3 Anhang zum Supporthandbuch 5](#_Toc196311233)

[4 Systemtest 5](#_Toc196311234)

[4.1 Testspezifikation 5](#_Toc196311235)

[4.1.1 Kritikalität der Funktionseinheit 5](#_Toc196311236)

[4.1.2 Testanforderungen 6](#_Toc196311237)

[4.1.3 Testverfahren 6](#_Toc196311238)

[4.1.4 Testkriterien 6](#_Toc196311239)

[4.1.5 Testfälle 6](#_Toc196311240)

[4.2 Testprozedur 7](#_Toc196311241)

[4.2.1 Vorbereitung 7](#_Toc196311242)

[4.2.2 Durchführung 7](#_Toc196311243)

[4.2.3 Nachbearbeitung 7](#_Toc196311244)

[4.3 Testprotokoll 8](#_Toc196311245)

[4.3.1 Testobjekt 8](#_Toc196311246)

[4.3.2 Testresultate 8](#_Toc196311247)

[4.3.3 Testauswertung 8](#_Toc196311248)

[5 Weiterführung der Projektplanung 8](#_Toc196311249)

[5.1 Abgleich von Planung und tatsächlichem Verlauf der Phase Konzept 8](#_Toc196311250)

[5.2 Aktualisierung der Risikosituation 8](#_Toc196311251)

[5.3 Planung der nächsten Phase 8](#_Toc196311252)

**Abbildungsverzeichnis**

Abb.1. Systemdesign Grafik / Autor: Naomi Bächler

# Zusammenfassung

In den folgenden Kapiteln wird die Realisierung des Projekts "Blackberry Pi Phone" detailliert aufgeführt. Dabei werden wesentliche Aspekte wie die tatsächliche Umsetzung des Projekts sowie die Resultate der Testing Fälle und unser weiteres Vorgehen. Das Ziel dieses Berichtes ist es, die gesamte Realisierung offen darzulegen und rückblickend zu urteilen, was wir besser machen konnte und was wir gut umsetzen.

# Technische Detailspezifikation

## Systemdesign

### Struktur

Image of the Systemdesign
Abb. 1. Systemdesign Grafik

### Beschreibung der Elemente

* Raspberry Pi Compute Module 5
* Blackberry Tastatur Tastatur aus einem alten Blackberry
* Waveshare Display 4.3inch DSI LCD
* Lipo Batterie 3.7V 5000mAh
* Side Fan DC12V - 0.18A Model: JD4512M12
* Nano Base Board Type A für Raspberry Pi Compute Module 5
* 3D-Gehäuse Die Druckpläne sind auf unserem [GitHub](https://github.com/PetabyteBrain/BlackberryPi/blob/main/README.md#3d-plans).

## Schnittstellendefinitionen

In der Oberen Abbildung ist auf allen wichtigen Pfeilen eine Art der Schnittstelle gekennzeichnet, hier eine Erläuterung:

* Tastatur: USB type A. Auf dem Base Board ist ein A Female, welcher die Tastatur entgegennimmt.
* Display: Ribbon Cable. Auf dem Base Board ist eine Ribbon Schnittstelle.
* Base Board: Board to Board 🡪 Das Raspberry und Base Board sind via mini Pins direkt verbunden.
* PMH: GPIO Pins 🡪 Base Board wird via GPIO Kabel und Jumper Wires (für länge) verbunden.
  + Batterie Conector 🡪 typischer Conector der mit Batterien kommt.
  + Jumper wires 🡪 Verlängerungskabel.

## Sicherheit (ISDS)

Wir achteten uns immer darauf, dass unsere Quellen glaubwürdig sind. Da unser Projekt open source ist, liegt es sehr offen und klar beim User, was er sich kauft, um das Projekt nachzustellen. Somit sind wir dort nicht verantwortlich für allgemeine Datenverschwendung.

## Anforderungszuordnung

|  |  |  |  |  |  |  |  |  |  |  |  |  |  |  |  |  |  |
| --- | --- | --- | --- | --- | --- | --- | --- | --- | --- | --- | --- | --- | --- | --- | --- | --- | --- |
| **AFo.-Nr.** | **Anforderung (Stichwort)** | **1** | **2** | **3** | **4** | **5** | **6** | **7** | **8** | **5** | **6** | **7** | **8** | **9** | **10** | **11** | **12** |
| 1 | Modularität |  |  |  |  |  |  |  |  |  |  |  |  |  | **x** |  |  |
| 2 | Hardware-Eingabegerät |  |  |  |  |  |  |  |  |  |  |  |  |  |  |  | **x** |
| 3 | Open Source |  |  |  |  |  |  |  |  |  |  |  |  |  |  |  | **x** |
| 4 | Austauschbarkeit |  |  |  |  |  |  |  |  |  |  |  |  |  |  |  | **x** |
| 5 | Stromversorgung (Akku) |  |  |  |  |  |  |  |  |  |  |  |  |  |  | **x** |  |
| 6 | Reparierbar/Reproduzierbar (3D-Druck) |  |  |  |  |  |  |  |  |  |  |  |  |  |  |  | **x** |
| 7 | Grundlegende Funktionen |  |  |  |  |  |  |  |  |  |  |  |  |  |  |  | **x** |
| 8 | Softwaremodifizierbarkeit |  |  |  |  |  |  |  |  |  |  |  |  |  |  |  | **x** |
| 9 | Kostengünstig |  |  |  |  |  |  |  |  |  |  |  |  |  |  |  | **x** |
| 10 | Technische Dokumentation |  |  |  |  |  |  |  |  |  |  |  |  | **x** |  |  |  |

# Systemdokumentation

## Konfigurations-Dokumentation

Die im Kapitel 2.1 aufgelisteten Elemente sind alle Hardwarekomponenten unseres Projektes, Software haben wir noch Scripts, welche jedoch schon vorgeschrieben sind. Um unser Projekt umzusetzen, braucht man vorinstalliert nur Raspberry Imager und den Raspberry Mass Storage Gadget. Die jeweiligen Ports, die wir nutzen, sind auch im Kapitel 2.2 aufgelistet. Die angesprochenen Scripts findet man im [GitHub](https://github.com/PetabyteBrain/BlackberryPi/blob/main/README.md#scripts).

## Benutzerhandbuch

### Systemübersicht

Unser Hauptziel ist es, ein portables, austauschbares, open source Telefon zu kreieren. Unser Telefon basiert auf einem Raspberry Pi, welches in ein Blackberry integriert wird. Die einzige externe Schnittstelle ist ein USB-Type-C-Kabel-Port, dieser wird gebraucht, um das Telefon aufzuladen. Da wir nicht mit Daten und sonstigen Informationen arbeiten, haben wir weder verschiedene Nutzer noch Schutzmassnahmen implementiert. Da unser Projekt open source ist, ist es in der Verantwortung jeden Users, sich selbst zu schützen.

### Anwenderfunktionalität

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

## Supporthandbuch

### Massnahmen bei Benutzerproblemen

Wir haben nicht wirkliche Benutzerprobleme, jedoch sind hier ein paar Stolpersteine.

* Noch keine SIM-Karte integriert
* Der Akku ist nicht lange andauernd

### Massnahmen bei technischen Problemen

Hier sind gefährliche technische Probleme und ihre Lösungen.

* Kabel reissen innert dem Telefon Neues Kabelbestellen und alte ersetzen
* Batterie Leer Neue Batterie kaufen und alte ersetzen
* Batterie ausgelaufen Telefon neu kreieren, sonst sehr gefährlich
* Lüfter defekt / überhitzt Neuer Lüfter kaufen und alter ersetzen
* Display defekt Neuer Display kaufen und alten ersetzen
* Tastatur Neue Tastatur /PCB/Kabel kaufen & ersetzen
* Boards kaputt (sehr unwahrscheinlich) Neue Boards kaufen oder gesamtes Telefon neu aufsetzen

### Anhang zum Supporthandbuch

Momentan haben wir noch keine Anhänge für das Supporthandbuch, da wir zum Beispiel keine Fehlermeldungen haben oder auch kein Glossar kreiert haben. Jedoch könnten in der Zukunft noch technische Erläuterungen oder sogar technische Übersichten angefügt werden. Wenn dies der Fall ist, werden wir dies in unserem Readme.md auf dem [GitHub](https://github.com/PetabyteBrain/BlackberryPi/blob/main/README.md) ergänzen!

# Systemtest

## Testspezifikation

### Kritikalität der Funktionseinheit

|  |  |  |
| --- | --- | --- |
| **Funktionseinheit** | **Kritikalität** | **Begründung** |
| Recheneinheit (Raspberry Pi) | Hoch | Ohne funktionierende Recheneinheit ist keine Systemfunktion möglich. |
| Stromversorgung (Akku) | Hoch | Das System ist ohne Stromversorgung nicht betriebsbereit. |
| Betriebssystem / Root-Zugriff | Hoch | Notwendig für alle weiteren Software-Tests und Anpassungen. |
| Tastatur (Hardware-Eingabe) | Mittel | Grundlegende Eingabe notwendig, jedoch durch Bildschirm ggf. ergänzbar. |
| WLAN | Mittel | Essentiell für viele Anwendungen, aber Systemstart auch offline möglich. |
| Gehäuse (3D-Druck) | Niedrig | Physisch wichtig, aber nicht kritisch für Softwarefunktionen. |

### Testanforderungen

Tests mit Normal-, Grenz- und Fehlerwerten.

Tests unter Ausnahmebedingungen (z. B. Akkuwechsel im Betrieb).

Alle Testergebnisse werden protokolliert.

### Testverfahren

Vorbereitung:

Komponenten anschließen, OS installieren, Stromversorgung sichern.

Durchführung:

Durchführung gemäß Testfalltabellen, manuell.

Auswertung:

Vergleich von Ist- mit Sollverhalten, Bewertung als „Bestanden / Nicht bestanden“.

### Testkriterien

Abdeckungsgrad: Mindestens ein Test pro Anforderung.

Checklisten: Alle Modul- und Systemfunktionen abgedeckt.

Ende-Kriterien: Keine Fehler in hochkritischen Modulen, System vollständig funktionsfähig.

### Testfälle

|  |  |  |  |  |  |  |
| --- | --- | --- | --- | --- | --- | --- |
| **Nr.** | **AFo-Nr.** | **Anwendungsfall (ggf. orientiert an Use Cases)** | **Ausgangs­situation** | **Eingabe­daten** | **erwartetes Ergebnis** | **Bemerkungen, Prüfergebnis** |
| T1 | A5 | Akku ausstecken | Gerät ist ausgeschaltet | Akku entfernen und wieder einsetzen | Gerät startet wie erwartet | Es funktioniert wie erwartet |
| T2 | A6 | Gehäuse prüfen (3D-Druck) | Gehäuseteile vorhanden | Zusammenbauen | Teile passen genau, Gerät sitzt fest |  |
| T3 | A7 | WLAN-Verbindung testen | WLAN verfügbar | SSID + Passwort eingeben | Verbindung bleibt stabil | Wlan lässt sich verbinden und es bleibt verbunden |
| T4 | A2 | Tastatureingabe testen | System betriebsbereit | Text eingeben | Zeichen werden korrekt dargestellt | Tastatur funktioniert |
| T5 | A8 | Konfigurationsdatei ändern | config.yaml geladen | Parameter ändern | Änderung zeigt Auswirkungen im Verhalten | Dies funktioniert |
| T6 | A9 | Budgetprüfung | Komponentenliste vorhanden | Preise eintragen | Gesamtkosten ≤ 250 € |  |
| T7 | A10 | Nachbau mit Doku | Nur Dokumentation vorhanden | Gerät nach Anleitung bauen | Gerät funktioniert wie geplant |  |

## Testprozedur

### Vorbereitung

OS-Installation auf SD-Karte abgeschlossen

Alle Module verbunden (ohne Kamera & Audio)

WLAN-SSID & Passwort bekannt

Voraussetzungen:
Alle Komponenten liegen vor und sind überprüft.

Tools zur Durchführung sind verfügbar.

Dokumentation für Referenztests ist vollständig und zugänglich.

Konfiguration:
Raspberry Pi in 3D-gedrucktem Gehäuse eingebaut.

Display, Tastatur und Akku korrekt verbunden.

Alle verwendeten Konfigurationsdateien befinden sich auf dem System.

Testumgebung: stabile Stromversorgung, lokales Netzwerk, stabile Tischunterlage für Gehäusetests.

### Durchführung

Initialisierung: System einschalten oder vorbereiten (z. B. Komponenten einsetzen).

Durchführung: Entsprechend des Testfalls Eingaben tätigen, Komponenten prüfen, Funktionen aufrufen oder physikalische Veränderungen vornehmen.

Beobachtung: Reaktion des Systems oder Moduls beobachten.

Vergleich: Ergebnis mit dem erwarteten Resultat aus der Testspezifikation vergleichen.

Dokumentation: Testausgang (Erfolg, Fehler, Besonderheiten) direkt erfassen.

### Nachbearbeitung

Auswertung der Resultate:

Das Ergebnis wird direkt nach jedem Testschritt dokumentiert (z. B. Tabelle oder digitales Protokoll).

Wenn nötig, werden Screenshots, Fotos oder Log-Dateien als Beleg gesichert.

Fehlermeldungen:

Auffälligkeiten (z. B. keine Reaktion, Bootfehler) werden mit Uhrzeit und Beschreibung festgehalten.

Bei Abweichung vom Soll: Testwiederholung und Prüfung der Fehlerquelle.

Protokollierung:

Ergebnisse werden in der Testprotokoll-Tabelle eingetragen (siehe 4.3.2).

Jede Abweichung wird auch im Abschnitt Testauswertung (4.3.3) kommentiert.

## Testprotokoll

### Testobjekt

Testobjekt: Raspberry-Pi-basiertes System mit modularer Bauweise (Version: v1.0)

Testfall: T1 – Akku entfernen und wieder einsetzen

Tester: Nicolas Ammeter

Ort: Innovationlab

Datum: 23.04.2025

Uhrzeit: 14:10 – 14:15 Uhr

### Testresultate

|  |  |  |  |
| --- | --- | --- | --- |
| **Zeitpunkt** | **Handlung** | **Beobachtung** | **Bewertung** |
| 14:10 Uhr | System ist ausgeschaltet | Keine Aktivität sichtbar | Erwartungsgemäß |
| 14:11 Uhr | Akku entnommen | Kein Widerstand, Stecker gut gelöst | Erwartungsgemäß |
| 14:12 Uhr | Akku wieder eingesetzt | Verbindung sitzt fest | Erwartungsgemäß |
| 14:13 Uhr | Gerät eingeschaltet (Power-Button) | LED leuchtet, System startet korrekt | **Bestanden** |

Erwartetes Ergebnis laut Spezifikation: Gerät startet nach Akkueinbau fehlerfrei → erfüllt

Zwischenergebnisse: Keine Zwischenstörungen, keine Verzögerung beim Boot

### Testauswertung

Abweichungen zur Spezifikation: Keine

Einfluss auf Funktionalität: Keine Einschränkung festgestellt. System funktioniert einwandfrei nach Akku-Wiedereinbau.

Mögliche Fehlerursachen: Keine aufgetreten

Trendbeobachtung: Keine Häufung ähnlicher Fehler – Test zeigt, dass die modulare Stromversorgung zuverlässig funktioniert.

# Weiterführung der Projektplanung

## Abgleich von Planung und tatsächlichem Verlauf der Phase Konzept

Wir kamen gut voran, die Teamarbeit funktionierte meist sehr gut und als wir Probleme antrafen, verloren wir nie die Hoffnung und das Telefon ist ein Erfolg geworden.

## Aktualisierung der Risikosituation

Es gab keine Veränderungen an der Risikosituation, die aktuelle Version ist im [Konzeptbericht](https://github.com/PetabyteBrain/BlackberryPi/blob/main/docs/Konzeptbericht.md).

## Planung der nächsten Phase

Unsere nächsten Tage besprechen wir noch die Präsentation und erstellen auch noch den Abschlussbericht.

Dies sollte in etwa so erfolgen:

**Spyros:** Abschlussbericht, Demo Vorbereitung

**Nicolas:** Präsentation, Demo Vorbereitung

**Naomi:** Abschlussbericht

**Aram:** Präsentation

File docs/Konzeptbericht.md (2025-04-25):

# Konzeptbericht

| **Status** | In Arbeit / In Prüfung / **Abgeschlossen** |
| --- | --- |
| **Projektname** | BlackBerry Pi |
| **Projektleiter** | Spyros Catéchis |
| **Auftraggeber** | Kurt Järmann |
| **Autoren** | Aram A., Nicolas A., Naomi B., Spyros C. |
| **Verteiler** | K. Järmann |

**Änderungskontrolle, Prüfung, Genehmigung**

|  |  |  |  |
| --- | --- | --- | --- |
| Version | Datum | Beschreibung, Bemerkung | Name oder Rolle |
| 1.0 | 22.04.2025 | Erste Ausfüllung | Aram, Naomi, Nicolas |
| 1.1 | 22.04.2025 | Raffinierung | Aram, Naomi |
| 1.2 | 22.04.2025 | Prüfung | Spyros |
| 1.3 | 22.04.2025 | Überarbeitung | Naomi |
| 2.0 | 22.04.2025 | Finale Abgabe | Spyros |

**Definitionen und Abkürzungen**

|  |  |
| --- | --- |
| Begriff / Abkürzung | Bedeutung |
| Pi | Raspberry Pi |
| AOSP | Android Open Source Projekt |
| BS | Betriebssystem |
| CAD | Computer Aided Design |
| BlackBerry Pi | Umbauprojekt: BlackBerry mit Raspberry Pi als Herzstück |

**Referenzen**

|  |  |
| --- | --- |
| Referenz | Titel, Quelle |
| Projektreferenzen | GitHub Repository | [GitHub-BlackBerryPi](https://github.com/PetabyteBrain/BlackberryPi) |

**Inhaltsverzeichnis**

[1 Zusammenfassung 3](#_Toc196211344)

[2 Systemanforderungen 3](#_Toc196211345)

[2.1 Anforderungen an die Funktionalität 3](#_Toc196211346)

[2.2 Anforderungen an die Informationssicherheit und den Datenschutz 4](#_Toc196211347)

[3 Systemarchitektur 4](#_Toc196211348)

[3.1 Gliederung der Lösung in Module 4](#_Toc196211349)

[3.2 Schnittstellen 4](#_Toc196211350)

[4 Testkonzept 5](#_Toc196211351)

[5 Weiterführung der Projektplanung 7](#_Toc196211352)

[5.1 Abgleich von Planung und tatsächlichem Verlauf der Phase Konzept 7](#_Toc196211353)

[5.2 Aktualisierung der Risikosituation 7](#_Toc196211354)

[5.3 Planung der nächsten Phase 8](#_Toc196211355)

# Zusammenfassung

In den folgenden Kapiteln wird die Konzeptualisierung des Projekts "Blackberry Pi Phone" detailliert behandelt. Dabei werden wesentliche Aspekte wie die benötigten Ressourcen für die Umsetzung des Projekts sowie die Vorgehensweise beim Testing thematisiert. Ziel ist es, eine klare und strukturierte Übersicht zu bieten, die die notwendigen Schritte und Überlegungen für die erfolgreiche Realisierung des Projekts darstellt.

# Systemanforderungen

## Anforderungen an die Funktionalität

Verfeinerte Anforderungen:

|  |  |  |  |
| --- | --- | --- | --- |
| **Anforderung** | **Bezeichnung** | **Beschreibung** | **Ziel(e)** |
| Modularität | A1 | Das System muss vollständig modular aufgebaut sein (Display, Akku, Recheneinheit, Eingabegeräte). | Z1 |
| Hardware-Eingabegerät | A2 | |  | | --- | |  |  |  | | --- | | Es muss ein Hardware-Eingabegerät vorhanden sein (z. B. physische Tastatur). | | Z3 |
| Open Source | A3 | Das Betriebssystem muss Open Source sein und Root-Zugriff ermöglichen. | Z1 |
| Austauschbarkeit | A4 | Alle Hardwarekomponenten müssen dokumentiert, öffentlich zugänglich und austauschbar sein. | Z2 |
| Stromversorgung (Akku) | A5 | Die Stromversorgung muss über einen austauschbaren Akku realisiert werden. | Z5 |
| Reparierbar/Reproduzierbar (3D-Druck) | A6 | Das Gehäuse muss reparierbar und z. B. durch 3D-Druck reproduzierbar sein. | Z5 |
| Grundlegende Funktionen | A7 | Das Gerät muss grundlegende Smartphone-Funktionen bieten (z. B. WLAN, Browser, Touchscreen). | Z4 |
| Softwaremodifizierbarkeit | A8 | Die Software muss leicht modifizierbar sein (z. B. durch Konfig-Dateien oder offene Quellcodes). | Z2 |
| Kostengünstig | A9 | Die Lösung muss kostengünstig realisierbar sein (< 250 CHF Gesamtbudget). | Z2 |
| Technische Dokumentation | A10 | Es muss eine ausführliche technische Dokumentation des Systems erstellt werden. | Z6 |

Systemaufgaben zur Erfüllung der Anforderungen:

|  |  |  |
| --- | --- | --- |
| **Aufgaben** | **Systemaufgabe** | **Bezug zu Anforderung(en)** |
| S1 | Auswahl, Beschaffung und Integration modularer Hardwarekomponenten (Display, Pi, Akku, Tastatur etc.) | A1, A4, A5 |
| S2 | Entwicklung oder Anpassung eines offenen Betriebssystems mit vollem Root-Zugriff | |  | | --- | |  | A3, A7, A8 |
| S3 | |  | | --- | |  | Design eines individuellen, 3D-druckbaren Gehäuses inkl. Öffnungen für Ports und Kühlung | A6, A1 |
| S4 | Test der Systemfunktionen: WLAN, Touchscreen, Browser | A7 |
| S5 | Implementierung einer physischen Eingabe (z. B. Mini-QWERTZ-Keyboard) | A2 |
| S6 | Detaillierte Dokumentation aller verwendeten Komponenten, Softwarestände und Konfigurationsschritte | A4, A10 |
| S7 | Kostenplanung, Preisvergleich und Budgetkontrolle während der Entwicklung | A9 |
| S8 | |  | | --- | |  | Einrichtung einer Entwicklungsumgebung für Softwaremodifikationen | A3, A8 |

## Anforderungen an die Informationssicherheit und den Datenschutz

In unserem Projekt wird nicht mit Informationen und Personendaten gehandelt. Somit sind unsere Anforderungen eher schlicht ausfallend. Für unser Team jedoch brauchen wir die folgenden Anforderungen.

1. Datenintegrität: Regelmässige Backups für Fortschritte zu abspeichern.
2. Dokumentation: Regelmässig Fortschritte mit einem Markup File dokumentieren.
3. Überprüfung: Regelmässig Testfälle überprüfen, um sicher zu stellen, das alles funktioniert.

# Systemarchitektur

## Gliederung der Lösung in Module

|  |  |  |
| --- | --- | --- |
| **Modul Nr.** | **Modulbezeichnung** | **Beschreibung** |
| M1 | Raspberry Pi | Zentrale Recheneinheit, die das Betriebssystem ausführt und die Kommunikation zwischen den Modulen steuert. |
| M2 | Touchscreen-Display | Anzeigeeinheit für die Benutzeroberfläche, ermöglicht die Interaktion durch Touch-Eingaben. |
| M3 | Physische Tastatur | Eingabemodul zur Text- und Befehlsübertragung über physische Tasten. |
| M4 | Gehäuse | Schutz und Halterung für alle Module, individuell gestaltbar. |
| M5 | Akku | Stromversorgung des gesamten Geräts. |
| M6 | Betriebssystem | Offenes Betriebssystem, das auf dem Raspberry Pi läuft und die Softwareumgebung bereitstellt. |
| M7 | Benutzeroberfläche | Anpassbare UI-Elemente, die die Interaktion mit dem Betriebssystem ermöglichen. |

## Schnittstellen

System – Extern

|  |  |  |  |
| --- | --- | --- | --- |
| Schnittstelle | Beschreibung | Datenübertragung | Konfiguration |
| S1 | WLAN/Bluetooth | Datenübertragung für Internet und Kommunikation | Über BS |
| S2 | USB-Schnittstelle | Verbindung zu externen Geräten | Über USB-C |

System – Intern

|  |  |  |  |
| --- | --- | --- | --- |
| S3 | GPIO-Schnittstelle | Steuerung und Kommunikation zwischen Modulen | Über BS |
| S4 | I2C-Schnittstelle | Kommunikation zwischen Display und Pi | Über BS |

# Testkonzept

|  |  |  |  |  |  |
| --- | --- | --- | --- | --- | --- |
| Systemaufgabe | Test-ID | Testbeschreibung | Testmethode / Eingabe | Erwartetes Ergebnis | Bezug zu Anforderung(en) |
| S1 – Modulare Hardwareintegration | S1-TF1 | Display einbauen und prüfen | Bildschirmmodul anschliessen | Bild wird angezeigt | A1 |
|  | S1-TF2 | Akku lösen | Akku einsetzen | Gerät startet ohne Fehler | A5 |
| S3 – 3D-druckbares Gehäuse | S3-TF1 | Gehäuse drucken nach STL-Datei | 3D-Drucker | Bauteil passt perfekt | A6 |
|  | S3-TF2 | Passgenauigkeit Gehäuse | Hardware einbauen | Alle Komponenten passen | A1, A6 |
|  | S3-TF3 | Stabilitätstest | Falltest aus 1 m Höhe | Kein Bruch / minimale Beschädigung | A6 |
| S4 – Grundfunktionen testen | S4-TF1 | WLAN-Verbindung prüfen | SSID + Passwort eingeben | Verbindung bleibt > 5 Min. | A7 |
| S5 – Eingabegerät | S5-TF1 | Tasteneingabe testen | Text eintippen | Text erscheint korrekt | A2 |
| S6 – Technische Dokumentation prüfen | S6-TF1 | Doku auf Vollständigkeit prüfen | Dokumentenreview | Alle Komponenten & Schritte enthalten | A10 |
|  | S6-TF2 | Doku-gestützter Nachbau durch Dritte | Gerät nach Anleitung bauen | Gerät funktioniert wie geplant | A10, A4 |
| S7 – Budgetkontrolle & Vergleich | S7-TF1 | Einzelpreise auflisten & summieren | Kostenaufstellung | Gesamt ≤ 250 € | A9 |
|  | S7-TF2 | Preisvergleich mit Marktgeräten | Vergleichsprodukte recherchieren | ≤ 50 % vom Durchschnittspreis | A9 |
| S8 – Softwareentwicklung & Modifikation | S8-TF1 | Entwicklungsumgebung einrichten | Toolchain installieren | Projekte bauen ohne Fehler | A3 |
|  | S8-TF2 | Konfigurationsdateien ändern | z. B. config.yaml anpassen | Änderungen wirken im System | A8 |

# Weiterführung der Projektplanung

## Abgleich von Planung und tatsächlichem Verlauf der Phase Konzept

Wir kamen gut voran müssen nur noch Modul Gehäuse abarbeiten und unsere Präsentation / Dokumentation anfertigen.
Wir hatten keine Zeitliche oder zwischenmenschliche Probleme. Das grösste Risiko war die Kompatibilität respektiv die Inkompatibilität der Hardware miteinander, vor allem war dies ein Störfaktor beim Display. Dies ist jedoch nur eine leichte Verzögerung und stellt keine Gefahr für die Abschliessung des Projektes dar.

## Aktualisierung der Risikosituation

* **1. Unklare Aufgabenverteilung oder Kommunikationsprobleme im Team**
* **Aktualisierung:** Die interne Kommunikation im Team ist sehr gut strukturiert und effizient. Es bestehen klare Absprachen, die regelmässig über Teams und in Meetings aktualisiert werden.
* **Risikoeinschätzung:**
  + *Eintretenswahrscheinlichkeit:* Gering
  + *Auswirkungen:* Mittel
* **Massnahmen in der Konzeptphase:**
  + Beibehaltung der bestehenden Kommunikationswege.
  + Weiterhin Nutzung von Kanban und regelmässigen Abstimmungen.
* **2. Unzureichende Ressourcen (Räumlichkeiten, IT-Infrastruktur)**
* **Aktualisierung:** Aktuell stehen die notwendigen Räumlichkeiten und IT-Ressourcen ohne Einschränkungen zur Verfügung.
* **Risikoeinschätzung:**
  + *Eintretenswahrscheinlichkeit:* Gering
  + *Auswirkungen:* Hoch
* **Massnahmen in der Konzeptphase:**
  + Regelmässiger Check der Infrastruktur.
  + Vorhalten eines alternativen Arbeitsplatzes bei Störungen.
* **3. Fehlende Abstimmung mit dem Auftraggeber**
* **Aktualisierung:** Erste Rücksprachen mit dem Auftraggeber fanden statt. Dennoch bleibt die Gefahr bestehend, dass Anforderungen missverstanden werden.
* **Risikoeinschätzung:**
  + *Eintretenswahrscheinlichkeit:* Mittel
  + *Auswirkungen:* Hoch
* **Massnahmen in der Konzeptphase:**
  + Regelmässige Feedbackrunden mit dem Auftraggeber.
  + Detaillierte Dokumentation aller Anforderungen und Rückmeldungen.
* **4. Zeitliche Engpässe im Team**
* **Aktualisierung:** Die Zeitplanung wurde realistisch gestaltet, und bisher konnten alle Aufgaben im vorgesehenen Rahmen erledigt werden.
* **Risikoeinschätzung:**
  + *Eintretenswahrscheinlichkeit:* Gering
  + *Auswirkungen:* Mittel
* **Massnahmen in der Konzeptphase:**
  + Fortführung der aktuellen Arbeitsplanung.
  + Beibehaltung von Pufferzeiten für unvorhergesehene Aufgaben

**5. Technische Komplexität der Hardwareintegration**

* **Beschreibung:** Die Verbindung verschiedener Hardwarekomponenten könnte zu unerwarteten technischen Schwierigkeiten führen.
* **Eintretenswahrscheinlichkeit:** Sehr gering
* **Auswirkungen:** Hoch
* **Massnahmen:**
  + Frühzeitige Prototyp-Tests.
  + Klare Dokumentation von Schnittstellen und Konfigurationen.

## Planung der nächsten Phase

Da wir fast fertig mit unserem Projekt sind, bleiben nur noch das Modul Gehäuse (wie oben beschrieben) und die formale Angaben/ die Dokumentationen. Dies Teilen wir uns im Team ca. wie unten beschrieben auf. Natürlich gibt es Interaktionen im Team, auch wenn der Plan anderes aussagt.

|  |  |  |  |
| --- | --- | --- | --- |
| WER | Di. 22. April | Mi 23. April | Fr. 25.April |
| Spyros | CAD-Modeling | Modeling 2.0 | PP | Präsentation & Demo |
| Aram | Konzept Doc | Realisierung Doc |PP | Abschluss Doc |
| Naomi | Konzept Doc | Realisierung Doc |PP | Abschluss Doc |
| Nicolas | CAD-Modeling | Modeling 2.0 | PP | Präsentation & Demo |

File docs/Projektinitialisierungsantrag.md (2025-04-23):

# Projektinitialisierungsantrag

|**Status** | In Arbeit / In Prüfung / **Abgeschlossen** |
| --- | --- |
| **Projektname** | Blackberry Pi |
| **Projektleiter** | Kurt Järmann |
| **Auftraggeber** | Kurt Järmann |
| **Autoren** | Aram Jan Amir, Spyros Catéchis |
| **Verteiler** | Kurt Järmann |

## Änderungskontrolle, Prüfung, Genehmigung

| **Version** | **Datum**  | **Beschreibung, Bemerkung** | **Name oder Rolle** |
|---|---|---|---|
| 1 | 27.11.2024 | Beginn Initialisierung | Aram / Spyros |

---

## Definitionen und Abkürzungen

| **Begriff / Abkürzung** | **Bedeutung** |
|---|---|
| Pi | Raspberry Pi |
| BlackBerry Pi | Umbauprojekt: BlackBerry mit Raspberry Pi als Herzstück |
|AOSP | Android Open Source Project|

---

## Referenzen

| **Referenz** | **Titel, Quelle** |
|---|---|
| [1] | [Blackberry Pi Artikel](https://magpi.raspberrypi.com/articles/blackberry-pi) |

---

## Inhaltsverzeichnis

1. Zweck des Dokuments  
2. Ausgangslage  
3. Ziele  
4. Rahmenbedingungen  
5. Aufwand  
6. Kosten  
7. Termine  
8. Ressourcen  
9. Kommunikation  
10. Risiken  
11. Projektinitialisierungsauftrag  

---

## 1. Zweck des Dokuments
Der Projektinitialisierungsauftrag bildet die verbindliche Grundlage für die Freigabe der Phase Initialisierung. Er ist die Vereinbarung zwischen Auftraggeber und Projektleiter.

---

## 2. Ausgangslage
- **Projektbeschreibung**: Das Projekt „Blackberry Pi“ soll ein herkömmliches BlackBerry-Smartphone mit einer modularen Hardwarelösung neugestalten. Ziel ist es, ein Retro-Smartphone mit moderner Technik auszustatten, sodass es mit einem modernen Betriebssystem läuft.
- **Problemstellung**: Aktuelle Smartphones mit physischer Tastatur sind rar. Dieses Projekt soll Fans der BlackBerry-Ästhetik eine kreative Alternative bieten. Moderne Smartphones werden immer grösser. Mit diesem Projekt soll ein kleineres Gerät angeboten werden, das als Lösung für dieses Problem dient.
- **Vorleistungen**: Erste Konzeptideen sowie technische Recherchen wurden abgeschlossen.

---

## 3. Ziele
- Integration moderner Hardware (Raspberry Pi) in das Gehäuse eines BlackBerry.  
- Sicherstellung der Funktionalität der BlackBerry-Tastatur und eines Raspberry-Pi-kompatiblen Displays.  
- Erstellung eines prototypischen Geräts mit funktionsfähigen Basisfeatures.  
- Entwicklung eines eigenen Betriebssystems für das Gerät (AOSP).

---

## 4. Rahmenbedingungen
- **Administrativ**: Genehmigungen und Projektplanung durch Autoren.  
- **Organisatorisch**: Unterstützung durch Lehrkräfte und Online-Ressourcen.  
- **Zeitlicher Rahmen**: Initialisierungsphase bis 29.11.2024.  
- **Projektmethode**: Hermes-Methode.  

---

## 5. Aufwand

### Arbeitsstunden
Der Zeitaufwand für das Projekt wird auf ungefähr **70 Stunden** geschätzt. Dies beinhaltet die folgenden Phasen:
- **Planung**: Recherche und Designphase, in der die Anforderungen und Spezifikationen festgelegt werden. Dazu gehört auch das Finden von geeigneten Hardware- und Softwarelösungen, die den Projektzielen entsprechen.
- **Aufbau und Implementierung**: Der praktische Teil des Projekts, bei dem die einzelnen Komponenten zusammengefügt werden. Hierzu zählen das Löten, die Verkabelung der Hardware, das Zusammenbauen des Gehäuses sowie das Installieren und Konfigurieren der Software.
- **Fehlerbehebung und Tests**: Nach der Implementierung wird eine Testphase durchgeführt, um sicherzustellen, dass alle Funktionen wie vorgesehen arbeiten. Dazu gehört das Debuggen von Softwareproblemen und die Optimierung der Hardware-Integration.

### Material
Für den Bau des Geräts werden verschiedene Komponenten und Materialien benötigt. Zu den Hauptbestandteilen gehören:
- **Gehäuse**: Ein robustes und anpassbares Gehäuse, das Platz für alle elektronischen Komponenten bietet. Es sollte auch ergonomisch sein und die Nutzung erleichtern.
- **Elektronische Bauteile**: Dazu zählen vor allem:
  - **Raspberry Pi** als Herzstück des Systems.
  - **Display** für die Benutzeroberfläche.
  - **Akku und Power-Management-Komponenten** zur Energieversorgung.
  - **Tastenfeld oder Touchscreen**, je nach Design.
  - **Module für Kommunikation** wie Wi-Fi, Bluetooth oder ein Mobilfunkmodem.
- **Zusätzliche Werkzeuge und Hilfsmittel**: Kabel, Lötstation, Schrauben, Isoliermaterialien und anderes Zubehör, das für die Montage erforderlich ist.

---

## 6. Kosten
- **Hardware-Komponenten (geschätzt)**:
	1. Gehäuse & Tastatur: 29,60 CHF
	2. Touchscreen: 14 CHF
	3. PCB für Tastatur: 65 CHF *eigentlicher preis: 0CHF durch [Onboard](https://hackclub.com/onboard/)*
	4. Tastatur connector: 24,29 CHF
	5. Raspberry pi: 20 - 80 CHF
	*End Kosten widersprechen nicht die oberen angaben*
- **Zusätzliche Materialien (Adapter, Kabel)**: ~  
- **Gesamtkosten**: 87,89 - 147,89 CHF 

---

## 7. Termine
- **Endtermin Initialisierung**: 27.11.2024.  
- **Studie**: 29.11.2024.  
- **Konzeptbericht**: 22.04.2025.  
- **Realisierungsbericht**: 23.04.2025.  
- **Projekt-Präsentation**: 25.04.2025.  
- **Schlussbericht**: 25.04.2025.  

---

## 8. Ressourcen
- **Technik**: Gehäuse eines BlackBerry-Smartphones, Peripherie.  
- **Werkzeuge**: Lötkolben, CAD-Software, 3D-Drucker.  
- **Support**: Online-Tools / Recherche, Lehrkraft.

---

## 9. Kommunikation
- **Stakeholder**: Auftraggeber, Autoren und Projektleiter.  
- **Form**: Zusammensetzung der Gruppenmitglieder beim Praxistraining, um den aktuellen Projektstatus zu besprechen. Die Ergebnisse werden schriftlich festgehalten. Dabei werden wichtige Punkte erkannt und nächste Ziele festgelegt. Dem Auftraggeber wird eine kurze Zusammenfassung des aktuellen Stands übermittelt.

---

## 10. Risiken
### Erkannte Risiken

1. **Unklare Aufgabenverteilung oder Kommunikationsprobleme im Team**:  
   - **Beschreibung**: Missverständnisse bei der Aufgabenverteilung oder fehlende Klarheit über Zuständigkeiten können zu Verzögerungen führen.  
   - **Eintretens-Wahrscheinlichkeit**: Mittel.  
   - **Auswirkungen**: Mittel – Ineffizientes Arbeiten, Verzögerungen im Zeitplan.  
   - **Massnahmen zur Minimierung**: Klare Kommunikation der Aufgabenverteilung im Teams-Chat, regelmässige Abstimmungsmeetings und tägliche Updates über den Fortschritt.  

2. **Unzureichende Ressourcen (Räumlichkeiten, IT-Infrastruktur)**:  
   - **Beschreibung**: Der Zugang zu den Gibb-Räumen oder zur IT-Infrastruktur könnte eingeschränkt sein, z. B. wegen technischer Probleme oder organisatorischer Hürden.  
   - **Eintretens-Wahrscheinlichkeit**: Gering.  
   - **Auswirkungen**: Hoch – Arbeitsunterbrechungen und Verzögerungen bei der Entwicklung.  
   - **Massnahmen zur Minimierung**: Alternativ auf den privaten Büroraum zugreifen und frühzeitig technische Probleme bei der IT-Abteilung melden.  

3. **Fehlende Abstimmung mit dem Auftraggeber**:  
   - **Beschreibung**: Unzureichende Kommunikation mit dem Auftraggeber könnte zu Missverständnissen in Bezug auf die Projektanforderungen führen.  
   - **Eintretens-Wahrscheinlichkeit**: Mittel.  
   - **Auswirkungen**: Hoch – Fehler in der Planung oder Missverständnisse in der Zielsetzung.  
   - **Massnahmen zur Minimierung**: Regelmässige Statusupdates per E-Mail, schnelle Rücksprache bei Unklarheiten via Teams.  

4. **Zeitliche Engpässe im Team**:  
   - **Beschreibung**: Die verfügbare Arbeitszeit pro Woche könnte nicht ausreichen, um alle Aufgaben im vorgegebenen Zeitraum abzuschliessen.  
   - **Eintretens-Wahrscheinlichkeit**: Mittel.  
   - **Auswirkungen**: Mittel – Verzögerungen beim Abschluss der Initialisierungsphase.  
   - **Massnahmen zur Minimierung**: Frühzeitige Planung und Priorisierung der Aufgaben, regelmässige Überprüfung des Fortschritts.  

---

## 11. Projektinitialisierungsauftrag
Hiermit erteilt der Auftraggeber den Auftrag zur Durchführung der Initialisierungsphase des Projektes „Blackberry Pi“.

| ________________________ | _________________________ |
|---|---|
| **Der Auftraggeber** | **Der Projektleiter** |
| *(Ort, Datum, Unterschrift)* | *(Ort, Datum, Unterschrift)* |

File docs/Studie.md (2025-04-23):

# Studie

| **Status** | In Arbeit / In Prüfung / **Abgeschlossen** |
| --- | --- |
| Projektname | Blackberry Pi |
| Projektleiter | Spyros Catéchis |
| Auftraggeber | Kurt Järmann |
| Autoren | Aram A. Naomi B. Spyros C. |
| Verteiler | Kurt Järmann |

**Änderungskontrolle, Prüfung, Genehmigung**

| Version | Datum | Beschreibung, Bemerkung | Name oder Rolle |
| --- | --- | --- | --- |
| V 1 | 29.11.24 | Beginn Studie | Aram / Naomi / Spyros |
|  |  |  |  |
|  |  |  |  |
|  |  |  |  |

**Definitionen und Abkürzungen**

| Begriff / Abkürzung | Bedeutung |
| --- | --- |
| Pi | Raspberry Pi |
| BlackBerry Pi | Umbauprojekt: BlackBerry mit Raspberry Pi als Herzstück |
| AOSP | Android Open Source Projekt |

**Referenzen**

| Referenz | Titel, Quelle |
| --- | --- |
| [1] | Blackberry Pi Artikel |

**Inhaltsverzeichnis**

[1 Situationsanalyse 3](#_Toc183806603)

[1.1 Ausgangslage 3](#_Toc183806604)

[1.2 Stärken 3](#_Toc183806605)

[1.3 Schwächen 3](#_Toc183806606)

[2 Ziele 4](#_Toc183806607)

[2.1 Rahmenbedingungen 4](#_Toc183806608)

[2.2 Abgrenzung 5](#_Toc183806609)

[3 Liste der Stakeholder 6](#_Toc183806610)

[4 Anforderungen 8](#_Toc183806611)

[5 Lösungsvarianten 8](#_Toc183806612)

[5.1 Variantenübersicht 8](#_Toc183806613)

[5.2 Beschreibung der Varianten 10](#_Toc183806614)

[6 Bewertung der Varianten (Tabelle) 11](#_Toc183806615)

[7 Lösungsbeschreibung 11](#_Toc183806616)

[8 Projektplanung 14](#_Toc183806617)

[9 Empfehlung 14](#_Toc183806618)

[10 Projektfreigabe 14](#_Toc183806619)

**Abbildungsverzeichnis**

Abb. 1 : Gantt-diagramm ; Excel Tabelle, N.B.

# Situationsanalyse

## Ausgangslage

Die Telefone von BlackBerry waren einst die unangefochtenen Marktführer im Smartphone-Bereich und besonders beliebt bei Geschäftskunden, da sie eine physische Tastatur, hohe Sicherheit und effiziente E-Mail-Verwaltung boten. Mit der Einführung des iPhones und der Touchscreen-Revolution durch Apple verschob sich der Fokus der Nutzer jedoch weg von Tastaturen hin zu grossen, interaktiven Displays. BlackBerry verpasste es, sich schnell genug anzupassen, und verlor schliesslich seinen Platz als Marktführer.

Heute ähneln sich die meisten Smartphones in Design und Funktionalität, was die Vielfalt am Markt stark eingeschränkt hat. In dieser homogenen Welt sehen wir eine Chance, BlackBerry neu zu interpretieren und etwas Einzigartiges zu schaffen.

Die bewährte BlackBerry-Architektur und die physische Tastatur bieten weiterhin viele Vorteile, insbesondere für Nutzer, die ein Gerät mit einer "echten" Tasteneingabe bevorzugen. Durch den Einsatz eines Raspberry Pi als Kern können wir die klassische Hardware mit moderner Technik kombinieren und ein Smartphone kreieren, das sowohl funktional als auch innovativ ist. Dieses neue Gerät vereint das Beste aus zwei Welten: Die Retro-Ästhetik und Haptik eines BlackBerry mit der Flexibilität und Leistungsfähigkeit eines Raspberry Pi – und bringt endlich wieder ein „neues Format“ auf den Smartphone-Markt.

## Stärken

*   Da die meisten Handys heutzutage ähnlich aussehen, hätten wir mit der Ästhetik des Blackberrys und der Tastatur einen Vorteil, da es anders als das Produkt der Konkurrenz ist. Dieses aussehen kann einen attraktiven Verkaufspunkt für Blackberry Enthusiasten sein.
*   Dazu haben wir den Vorteil, dass wir unser Produkt Open Source behalten und deswegen jeder Nutzer genau wissen kann, was es beinhaltet und was er eingeht beim Gebrauch unserer Software.
*   Kosteneffiziente Hardware, Beispiel Raspberry Pi. Der Vorteil davon ist, dass die Reparaturen einfach vom Nutzer / einem Dienst gemacht werden können und günstiger wären als andere moderne Handys.
*   Das Blackberry Pi kann auch mit anderen Betriebssystemen laufen, solange es mit den Drivern und Hardware kompatibel ist.
*   Da es Open Source ist, kann es die Möglichkeit geben, Anpassungen am Gerät zu führen, um diese Benutzerspezifisch zu gestalten und zu entwickeln.

## Schwächen

Hohe Abhängigkeit von proprietärer Software (S1):

Viele Nutzer sind auf geschlossene OS (z.B. iOS, Android) angewiesen. Ein offenes, anpassbares System basierend auf Raspberry Pi kann die Abhängigkeit reduzieren.

Hohe Kosten moderner Smartphones (S2):

Premium-Smartphones sind oft sehr teuer. Ein DIY-Handy auf Basis eines Raspberry Pi bietet eine kostengünstige Alternative, insbesondere für technikaffine Nutzer.

Komplizierte Reparierbarkeit (S3):

Viele aktuelle Smartphones sind schwierig zu reparieren (z.B. durch verklebte Komponenten). Unser Projekt kann durch ein modulares Design mit leicht austauschbaren Teilen punkten.

Mangelnde Software-Upgrades bei älteren Geräten (S4):

Hersteller unterstützen ältere Modelle oft nicht mehr mit Updates, was Sicherheitsrisiken birgt. Ein offenes System erlaubt langfristige Pflege und Updates durch die Community.

Eingeschränkte Anpassbarkeit (S5):

Nutzer können Design, Funktionen und Hardware ihrer Smartphones nur begrenzt anpassen. Mit einem Raspberry Pi sind massgeschneiderte Anpassungen möglich.

# Ziele

Freie OS Wahl(Z1):

Mit einer freien resp. unabhängigen OS Wahl ist die Bandbreite des Blackberrys viel besser und man kann.

(referenziert S1)

Kosten & Marken (Z2):

Solange man nicht nur für die Marke bezahlt ist ein Smartphone schon sehr viel billiger, wenn wir dies mit simpler Technologie verknüpfen, bekommen wir ein einfaches Telefon und faires Preis-Leistung Verhältnis.

(referenziert S2)

Simple Technologie(Z3):

Da wir unser Blackberry Pi mit einem Raspberry Pi ausstatten, ein Screen und noch eine Tastatur hinzufügen ist das ganze Telefon sehr simpel und wenn ein Natel simpel ist, ist es auch simpel zum Reparieren. Was vor allem für ein kostengünstiges design ein Schlüsselziel ist.

(referenziert S3)

Sicherstellung langfristiger Software-Upgrades durch ein offenes System (Z4):

Das Projekt BlackBerry Pi zielt darauf ab, ein Smartphone mit einem offenen Betriebssystem zu entwickeln, das von der Community unterstützt werden kann. Dadurch wird es Nutzern ermöglicht, regelmässig Sicherheitsupdates und neue Funktionen zu erhalten, unabhängig von der Herstellerunterstützung. Dies reduziert Sicherheitsrisiken und verlängert die Nutzungsdauer des Geräts erheblich.

(referenziert S4)

Personalisierung(Z5):

Durch die simple Technologie und die freie OS-wahl ist das Natel individualisierbar. Das heisst der Nutzer kann alles personalisieren, eigene teile zum Telefon zusammenstellen. Wenn der Nutzer sehr viel Technik wissen hat, könnte er sogar zuhause sein Handy personalisieren.

(referenziert S5)

## Rahmenbedingungen

1.  **Zeitliche Rahmenbedingungen**

*   Projektzeitraum:

Das Projekt startet in **KW48** und endet in **KW17**. Innerhalb dieses Zeitraums werden alle wichtigen Meilensteine erreicht, darunter die Planung, praktische Umsetzung und abschliessende Präsentation.

*   Regelmässige Termine:

Wöchentliche Arbeitseinheiten finden im Rahmen des Praxistrainings am Freitagmorgen statt. Dieser regelmässige Zeitblock wird genutzt, um Fortschritte im Projekt zu erzielen und spezifische Aufgaben zu bearbeiten.

1.  **Räumliche Rahmenbedingungen**

*   Arbeitsort:

Die praktischen Arbeiten wie Zusammenbau, Tests und andere Projektschritte werden im Gibb Praxistraining durchgeführt. Hier stehen die notwendigen Ressourcen und Werkzeuge für die Umsetzung zur Verfügung.

1.  **Organisatorische Rahmenbedingungen:**

*   Verantwortlichkeiten:

Der Projektverantwortliche ist Michael Peter, der die übergreifende Koordination übernimmt.

Das Praxistraining wird vom Auftragsgeber geführt, der die praktische Umsetzung und Betreuung leitet.

## Abgrenzung

Die Abgrenzung definiert, welche Aspekte und Bereiche das Projekt _BlackBerry Pi_ nicht abdeckt, um den Umfang klar zu definieren und Missverständnisse zu vermeiden. Dies hilft, Fokus und Ressourcen gezielt einzusetzen. Im Folgenden werden einige Ideen und Beispiele aufgeführt:

1.  **Ideen zur Abgrenzung**

*   **Kommerzialisierung und Serienproduktion**
    *   Das Projekt ist rein prototypisch und wird keine grossflächige Serienproduktion oder Vermarktung umfassen.
    *   Beispiel: Es wird keine umfassende Marketingkampagne erstellt oder Logistik für den Verkauf organisiert.
*   **Entwicklung von Drittanbieter-Software**
    *   Das Projekt umfasst die Installation eines Betriebssystems, jedoch keine Entwicklung komplexer Software oder Apps von Grund auf.
    *   Beispiel: Die Anpassung bestehender Apps an das System wird nicht durchgeführt.
*   **Vollständige Kompatibilität mit BlackBerry-Diensten**
    *   Historische BlackBerry-Dienste wie BBM (BlackBerry Messenger) oder BlackBerry-Serverintegration werden nicht reaktiviert oder unterstützt.
    *   Beispiel: Die E-Mail-Push-Funktion von alten BlackBerry-Geräten wird nicht wiederhergestellt.
*   **Hardware-Optimierung auf Industrie-Standard**
    *   Es wird kein auf Effizienz oder Produktionskosten optimiertes Motherboard entwickelt, sondern ein Raspberry Pi genutzt.
    *   Beispiel: Statt einer massgeschneiderten Platine bleibt der Fokus auf der Integration bestehender Komponenten.
*   **Langfristiger Support und Wartung**
    *   Das Projekt wird keine langfristige Pflege des Betriebssystems oder regelmässige Updates garantieren.
    *   Beispiel: Sicherheitsupdates oder neue Features nach der Projektlaufzeit sind nicht vorgesehen.

1.  **Beispiele für typische Ausschlüsse bei einem solchen Projekt**

*   **Mobilfunkzertifizierung**
    *   Das Projekt wird keine umfassende Zertifizierung für den Einsatz in Mobilfunknetzen vornehmen.
    *   Beispiel: Keine Freigabe von Mobilfunkanbietern für LTE/5G.
*   **Multiplattform-Unterstützung**
    *   Es wird nicht darauf abgezielt, das Betriebssystem auf andere Geräte zu portieren.
    *   Beispiel: Der Prototyp bleibt auf das BlackBerry-Gehäuse beschränkt.
*   **Umfassende Benutzeroberfläche**
    *   Es wird keine voll ausgereifte Benutzeroberfläche wie bei kommerziellen Betriebssystemen erstellt.
    *   Beispiel: Minimalistische Funktionalität reicht aus, z. B. für grundlegende Kommunikation oder Terminal-Anwendungen.
*   **Hohe Produktionsqualität**
    *   Da es sich um einen Prototyp handelt, wird keine perfekte Anpassung oder Veredelung der Hardware erfolgen.
    *   Beispiel: Das Gehäuse könnte sichtbare Modifikationen wie Schraublöcher oder zusätzliche Kabel aufweisen.
*   **Komplette Rückwärtskompatibilität**
    *   Das Gerät wird nicht die Fähigkeit haben, alle historischen Funktionen und Anwendungen eines BlackBerry vollständig zu reproduzieren.
    *   Beispiel: Die originale BlackBerry-OS-Funktionalität wird nicht unterstützt.

1.  **Fazit zur Abgrenzung**

Die Abgrenzung soll verhindern, dass das Projekt über seine Kapazitäten hinauswächst. Der Fokus liegt auf einem funktionalen Prototyp, der die Idee eines BlackBerry-Smartphones mit Raspberry-Pi-Kern demonstriert. Bereiche wie Kommerzialisierung, umfangreiche Softwareentwicklung oder langfristiger Support bleiben bewusst ausserhalb des Projektumfangs.

# Liste der Stakeholder

Das Projekt _BlackBerry Pi_ hat verschiedene Stakeholder, die entweder direkt in die Entwicklung und Umsetzung einbezogen sind oder indirekt von den Ergebnissen des Projekts profitieren oder beeinflusst werden. Die Stakeholder lassen sich in folgende Kategorien unterteilen:

1.  **Primäre Stakeholder (direkt betroffen):**

*   **Kunde**
    *   Endnutzer des Geräts, die ein Interesse an einem Smartphone mit physischer Tastatur und modernem Betriebssystem haben.
    *   Erwartungen: Ein hochwertiges, funktionsfähiges und innovatives Gerät, das Retro-Charme mit moderner Technik verbindet.
*   **Entwickler & Projektmanager**
    *   Projektteam, bestehend aus Entwicklern und dem Projektleiter, das für die technische Umsetzung und die Organisation des Projekts verantwortlich ist.
    *   Erwartungen: Klare Anforderungen, Ressourcen, realistische Zeitpläne und Unterstützung durch den Auftraggeber.
*   **Auftraggeber**
    *   Kurt Järmann, der das Projekt ins Leben gerufen hat und als Schnittstelle zwischen Team und Kunde fungiert.
    *   Erwartungen: Ein funktionierender Prototyp, der die Machbarkeit des Konzepts beweist.

1.  **Sekundäre Stakeholder (indirekt betroffen):**

*   **Geldgeber & Investoren**
    *   Personen oder Institutionen, die die finanziellen Mittel bereitstellen, um die Entwicklung zu ermöglichen.
    *   Erwartungen: Transparente Kommunikation, nachvollziehbare Kostenpläne und eine realistische Aussicht auf zukünftige Renditen oder Marktinteresse.
*   **Technikbegeisterte**
    *   Enthusiasten und Maker, die sich für DIY-Technologie und innovative Hardwarelösungen interessieren.
    *   Erwartungen: Detaillierte Dokumentation und eventuell Open-Source-Freigabe der Projektdaten, um Nachbauten zu ermöglichen.
*   **Konkurrenten**
    *   Andere Unternehmen oder Projekte, die sich mit Retro-Technologie oder innovativen Smartphones beschäftigen.
    *   Erwartungen: Aufmerksamkeit auf dem Markt, Interesse an der Strategie und potenzielle Wettbewerbsvorteile durch eigene Innovationen.

1.  **Weitere Stakeholder:**

*   **Geschäftsleitung und betroffene Abteilungen der Stammorganisation**
    *   Interne Gruppen, die über den Fortschritt des Projekts informiert werden müssen, wie z. B. Marketing und Vertrieb, falls das Produkt kommerzialisiert wird.
*   **Ämter und Regulierungsbehörden**
    *   Institutionen, die eventuell für rechtliche Genehmigungen und Zertifizierungen bei einer möglichen Markteinführung des Geräts benötigt werden.
*   **Medien und Öffentlichkeit**
    *   Technologie-Journalisten und Interessierte, die über den Fortschritt und die Ergebnisse des Projekts berichten könnten.

1.  **Kommunikation mit Stakeholdern**

Es ist wichtig, regelmässig und zielgerichtet mit den Stakeholdern zu kommunizieren:

*   **Kunden** erhalten Updates über den Entwicklungsstand.
*   **Entwickler und Projektleiter** führen tägliche Abstimmungen durch.
*   **Geldgeber und Investoren** werden in Meetings über Budget und Fortschritte informiert.
*   **Technikbegeisterte** könnten über Blogs oder Foren eingebunden werden, um Feedback zu erhalten und Interesse zu wecken.
*   **Medien und Öffentlichkeit** werden über fertige Prototypen und Innovationen in einer Pressemitteilung informiert.

# Anforderungen

| Anforderung | Bezeichnung | Beschreibung | Ziel(e) |
| --- | --- | --- | --- |
| Offene Software-Architektur | A1 | Das System muss auf einem offenen Betriebssystem basieren, das langfristige Software-Upgrades und Anpassungen durch die Community ermöglicht. | Z1, Z4 |
| Modulares Hardware-Design | A2 | Das Telefon muss so konstruiert sein, dass Komponenten wie Display, Tastatur oder Akku einfach ausgetauscht oder aktualisiert werden können. | Z3 |
| Freie Betriebssystemwahl | A3 | Es soll möglich sein, verschiedene Betriebssysteme (z. B. Linux-Distributionen) auf dem Gerät zu installieren und zu nutzen. | Z1, Z5 |
| Kosteneffizienz | A4 | Die verwendeten Komponenten müssen günstig sein, sodass das Gerät ein faires Preis-Leistungs-Verhältnis bietet und unter den Kosten gängiger Smartphones bleibt. | Z2 |
| Einfache Reparierbarkeit | A5 | Das Telefon soll mit Standardwerkzeugen leicht zu reparieren sein, um die Lebensdauer zu verlängern und Nachhaltigkeit zu fördern. | Z3 |
| Hohe Anpassbarkeit | A6 | Nutzer sollen das Gerät sowohl in Hardware (z. B. Gehäuse-Design) als auch in Software (z. B. Benutzeroberfläche) individuell anpassen können. | Z5, Z1 |

# Lösungsvarianten

## Variantenübersicht

**1\. Gekauftes Handy von Blackberry**

*   **Beschreibung:  
    Erwerb eines bestehenden Modells, wie z. B. des BlackBerry Key2.**
*   **Vorteile:**
    *   **Fertiges Produkt ohne Entwicklungsaufwand.**
    *   **Sofort einsatzbereit und zuverlässig.**
    *   **Professionelles Design und getestete Hardware.**
*   **Nachteile:**
    *   **Hohe Kosten im Vergleich zum Eigenbau.**
    *   **Einschränkungen bei Anpassungen (Hard- und Software).**
    *   **Abhängigkeit von Hersteller-Updates und proprietären Systemen.**
*   **Link zur Beschreibung:  
    **[**BlackBerry Key2 auf Wikipedia**](https://en.wikipedia.org/wiki/BlackBerry_Key2)

**2\. Eigener Prototyp zusammenbauen**

*   **Beschreibung:  
    Eigenbau eines Blackberry-Pi-Handys durch die Kombination von modularer Hardware und frei verfügbarer Software.**
*   **a. Hardware**
*   **Komponenten:**
    *   **Raspberry Pi: Als Hauptrechner (z. B. Pi Zero 2 W oder Pi 4).**
    *   **Display: Kleines Touchscreen-Display (z. B. 3.5 Zoll LCD).**
    *   **Tastatur: Physische Tastatur (z. B. DIY-Module oder vorgefertigte Lösungen).**
    *   **Gehäuse: Eigenbau, z. B. aus 3D-Druckteilen.**
    *   **Zusatzmodule: Kamera, Akku, Lautsprecher und Mikrofon.**
*   **b. Software**
*   **Betriebssystem: Installation eines freien Betriebssystems wie Raspberry Pi OS, Ubuntu oder LineageOS.**
*   **Vorteile:**
    *   **Maximale Anpassungsfähigkeit und Kosteneffizienz.**
    *   **Open-Source-Software ermöglicht langfristige Updates und Pflege.**
    *   **Lern- und Innovationspotenzial.**
*   **Nachteile:**
    *   **Zeitintensiv und technisch anspruchsvoll.**
    *   **Mögliche Inkompatibilitäten zwischen Komponenten.**

**3\. Modifikation eines bestehenden Smartphones**

*   **Beschreibung:  
    Anpassung eines vorhandenen Smartphones, indem Software ersetzt wird und Hardware soweit möglich modifiziert wird.**
*   **a. Hardware-Anpassungen**
*   **Basisgerät: Nutzung eines alten oder kostengünstigen Smartphones, das bereits eine physische Tastatur besitzt (z. B. ältere Blackberry-Modelle).**
*   **Zusatzmodule: Externe Tastaturen, neue Gehäuse oder Austausch von Komponenten wie Akku.**
*   **b. Software-Anpassungen**
*   **Custom ROMs: Installation eines freien Betriebssystems wie LineageOS, /e/OS oder anderen angepassten Android-Versionen.**
*   **Optimierung: Entfernen von Bloatware und Hinzufügen von sicherheitsorientierten Apps.**
*   **Vorteile:**
    *   **Schneller und weniger zeitaufwendig als ein kompletter Eigenbau.**
    *   **Kosteneinsparung durch die Wiederverwendung bestehender Geräte.**
    *   **Direkter Fokus auf Nachhaltigkeit und Ressourcenschonung.**
*   **Nachteile:**
    *   **Begrenzte Anpassbarkeit der Hardware.**
    *   **Mögliche Inkompatibilitäten bei Softwaremodifikationen.**
    *   **Gerät bleibt abhängig von der ursprünglichen Hardwarequalität.**

**4\. Nutzung eines älteren Smartphones mit angepasstem Open-Source-Betriebssystem**

*   **Beschreibung:  
    Verwendung eines älteren, gebrauchten Smartphones (z. B. ein älteres Android-Gerät) und Installation eines offenen Betriebssystems wie LineageOS oder /e/OS. Dieses Vorgehen ermöglicht es, ein funktionales, kostengünstiges Smartphone zu erstellen, das an die eigenen Bedürfnisse angepasst werden kann, ohne ein Gerät von Grund auf neu zu bauen.**
*   **a. Hardware**
*   **Basisgerät: Ein günstiges, gebrauchtes oder älteres Smartphone (z. B. ein älteres Android-Gerät oder ein gebrauchtes Gerät von Marken wie Fairphone oder Nexus).**
*   **Anpassungen: Gegebenenfalls werden einfache Hardware-Anpassungen vorgenommen, wie der Austausch des Akkus oder das Hinzufügen von Zubehör (z. B. einer physischen Tastatur).**
*   **b. Software**
*   **Betriebssystem: Installation eines offenen, freien Betriebssystems wie LineageOS oder /e/OS. Diese Systeme bieten regelmässige Updates und die Freiheit, die Software an die eigenen Anforderungen anzupassen.**
*   **Optimierung: Entfernen von Bloatware, Anpassung der Benutzeroberfläche und Installation sicherer, funktioneller Apps.**
*   **Vorteile:**
*   **Kostenersparnis: Die Nutzung eines gebrauchten Smartphones ist deutlich günstiger als der Bau eines eigenen Geräts.**
*   **Schnelle Umsetzung: Die Anpassung eines bestehenden Geräts dauert weniger Zeit als der Eigenbau.**
*   **Zukunftssicher: Die Nutzung eines offenen Betriebssystems bedeutet, dass regelmässige Updates und Sicherheits-Patches von der Community bereitgestellt werden.**
*   **Nachhaltigkeit: Wiederverwendung und Recycling von Geräten verringert den Elektronikmüll.**
*   **Nachteile:**
*   **Begrenzte Anpassbarkeit der Hardware: Die Hardware kann nicht vollständig angepasst werden, da sie auf einem bestehenden Gerät basiert.**
*   **Abhängigkeit von der ursprünglichen Hardwarequalität: Das Endprodukt ist immer noch an die Begrenzungen der Originalhardware gebunden.**

## Beschreibung der Varianten

**1\. Eigener Prototyp zusammenbauen**

*   **Beschreibung**:  
    Der erste Schritt besteht darin, ein eigenes Gerät von Grund auf zu bauen, indem man Hardware und Software kombiniert. Der Hauptbaustein ist ein **Raspberry Pi**, auf dem ein offenes Betriebssystem läuft. Dazu kommen ein kleines Touchscreen-Display, eine physische Tastatur und eine individuelle Gehäusekonstruktion, die entweder selbst designt oder durch 3D-Druckteile erstellt wird. Die Komponenten wie Kamera, Lautsprecher und Mikrofon können ebenfalls je nach Bedarf hinzugefügt werden. Diese Variante bietet die grösste Anpassungsfreiheit, da sowohl die Hardware als auch die Software nach den eigenen Anforderungen gestaltet werden können.  
    Das Ziel ist es, ein funktionales Smartphone zu bauen, das langfristig pflegbar ist und mit den neuesten Software-Updates versorgt werden kann. Dies bedeutet jedoch, dass der Entwicklungsaufwand und die technische Komplexität relativ hoch sind.

**2\. Modifikation eines bestehenden Smartphones**

*   **Beschreibung**:  
    Bei dieser Variante wird ein bestehendes Smartphone verwendet, das bereits grundlegende Funktionen erfüllt, aber durch Modifikationen in Hardware und Software den individuellen Anforderungen angepasst wird. Als Basisgerät könnte ein älteres, kostengünstiges Modell gewählt werden. Eine typische Wahl sind Geräte mit physischen Tasten, wie die älteren **Blackberry-Modelle**.  
    In Bezug auf Software wird ein offenes Betriebssystem wie **LineageOS** oder **/e/OS** aufgespielt, um die Kontrolle über Updates und Anpassungen zu behalten. In der Hardware können Komponenten wie der Akku ausgetauscht oder eine externe Tastatur hinzugefügt werden, um die Bedienbarkeit zu verbessern. Diese Variante ist weniger aufwendig als der komplette Eigenbau, erfordert jedoch auch einige technische Fähigkeiten und bietet nicht die gleiche Flexibilität wie der Prototypenbau.

**3\. Nutzung eines älteren Smartphones mit angepasstem Open-Source-Betriebssystem**

*   **Beschreibung**:  
    Bei dieser Lösung wird ein älteres, gebrauchtes Smartphone genutzt, das mit einem Open-Source-Betriebssystem wie **LineageOS** oder **/e/OS** ausgestattet wird. Das Ziel ist es, ein funktionales Smartphone zu schaffen, das an die eigenen Bedürfnisse angepasst ist und von der Community regelmässig mit Updates versorgt wird. Hierbei liegt der Fokus auf der Software und der Minimierung der Bloatware, während die Hardware weitgehend unverändert bleibt.  
    Ein Vorteil dieser Lösung ist die Kosteneffizienz, da gebrauchte Geräte oft zu einem Bruchteil des Preises eines neuen Smartphones erhältlich sind. Es handelt sich um eine schnelle und nachhaltige Lösung, da alte Geräte wiederverwendet und für eine moderne Nutzung optimiert werden. Diese Variante ist besonders für Nutzer geeignet, die Wert auf ein einfaches, funktionales Gerät legen, ohne tief in die Hardware-Entwicklung eingreifen zu müssen.

**4\. Gekauftes Handy von Blackberry**

*   **Beschreibung**:  
    Die einfachste Variante besteht darin, ein bestehendes Modell, wie z. B. das **BlackBerry Key2**, direkt zu kaufen. Dies ist die Lösung mit dem geringsten Aufwand, da das Gerät sofort einsatzbereit ist. Die Blackberry-Geräte bieten eine bewährte Hardware, die für Business-Anwendungen und effiziente Textbearbeitung optimiert ist. Ein Vorteil dieser Option ist die Zuverlässigkeit des Produkts und das professionelle Design, das gut getestet ist.  
    Allerdings gibt es bei dieser Variante Einschränkungen, wenn es um die Anpassung der Software und die Kontrolle über Updates geht. Man ist weiterhin auf den Hersteller angewiesen, was in Bezug auf langfristige Updates und die Freiheit, das Gerät nach eigenen Wünschen zu gestalten, problematisch sein kann. Zudem sind die Kosten im Vergleich zu den anderen Varianten relativ hoch, und man zahlt auch für die Marke.

# Bewertung der Varianten (Tabelle)

| Kriterien | Gewichtung | Eigener Prototyp | Modifikation | Open-Source-Gerät | Blackberry kaufen |
| --- | --- | --- | --- | --- | --- |
| Anpassungsfähigkeit | 25% | 5 | 4 | 3 | 1 |
| Lernpotenzial & Innovation | 20% | 5 | 3 | 2 | 1 |
| Kosten | 20% | 3 | 4 | 5 | 2 |
| Unabhängigkeit | 15% | 5 | 3 | 3 | 1 |
| Komplexität | 15% | 2 | 4 | 5 | 5 |
| Nachhaltigkeit | 5% | 4 | 5 | 5 | 2 |
| Gesamtbewertung | 100% | 4.4 | 3.8 | 3.4 | 2.0 |

**1: Eigener Prototyp zusammenbauen (4.4 Punkte)**  
Diese Variante wird nun als beste Lösung bewertet, da sie maximale Anpassungsfähigkeit, Unabhängigkeit und Lernpotenzial bietet. Sie ist besonders geeignet für Projekte, die auf Innovation und langfristige Kontrolle abzielen.

**2: Modifikation eines bestehenden Smartphones (3.8 Punkte)**  
Eine solide Lösung mit hoher Nachhaltigkeit und moderatem Aufwand. Jedoch begrenzt in der Anpassungsfähigkeit im Vergleich zum Eigenbau.

**3: Nutzung eines älteren Smartphones mit Open-Source-Betriebssystem (3.4 Punkte)**  
Eine pragmatische, kostengünstige Lösung, die jedoch weniger Lernpotenzial und Hardware-Freiheit bietet.

**4: Gekauftes Handy von BlackBerry (2.0 Punkte)**  
Die schlechteste Option in diesem Szenario, da sie weder Anpassungsfähigkeit noch Unabhängigkeit bietet und teuer ist.
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

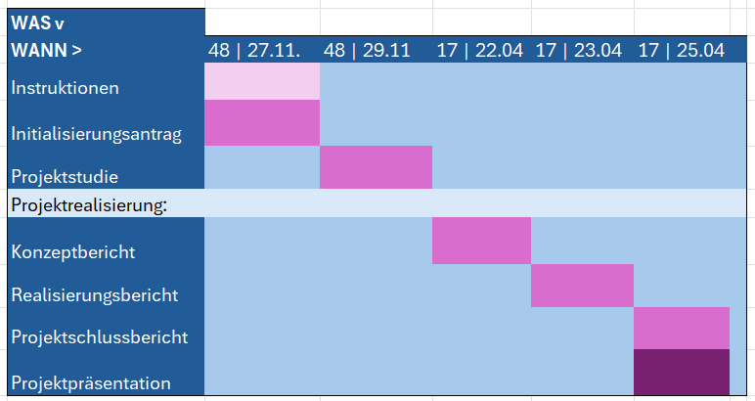
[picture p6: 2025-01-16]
docs/Images/Projektplanung.png

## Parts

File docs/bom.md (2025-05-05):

# Bill of Materials (BOM)

This document lists all hardware components used in the BlackBerry Pi project, including links, approximate prices, and quantities.

| Item | Quantity | Description | Source / Link | Est. Price (USD) |
|---|---|---|---|---|
| Raspberry Pi Compute Module 5 | 1 | CM5 with 16GB RAM + Wi-Fi | [Welectron](https://www.welectron.com/Raspberry-Pi-Compute-Module-CM5104016-16GB-4-GB-RAM-WLAN) | ~70 |
| Waveshare Nano Base Board A | 1 | Baseboard for CM5 | [Waveshare](https://www.waveshare.com/cm5-nano-a.htm) | ~30 |
| 4.3" DSI LCD Display | 1 | Waveshare 4.3" DSI LCD | [Waveshare](https://www.waveshare.com/4.3inch-dsi-lcd.htm) | ~35 |
| Power Management HAT (B) | 1 | Power HAT for Pi with battery support | [Waveshare](https://www.waveshare.com/power-management-hat-b.htm) | ~20 |
| LiPo Battery 3.7V 5000mAh | 1 | Battery powering the system | [Generic vendors] | ~15 |
| DC Brushless Fan JD4512M12 | 1 | 12V cooling fan | eBay / 3D printer spare parts vendors | ~5 |
| USB-C Female to Male Extension | 1 | For relocating USB-C port | DIY / generic | ~2 |
| USB-A to open-end cable | 1 | Keyboard to CM5 connection | DIY | ~1 |
| Blackberry Q10 Keyboard | 1 | Requires Fairberry mod | eBay / Ricardo / Used | ~5–15 |
| Screws (2.5 mm) | 17 | For mounting various internal components | Hardware store | ~2 |
| Jumper Wires | ~20-25 | For fan & other pin connections | Generic | ~1 |
| 3D Printed Case Parts | 3 | Front, Main, Back panels | See `docs/models/` | n/a |

> ⚠️ Prices are rough estimates and may vary depending on region or supplier.

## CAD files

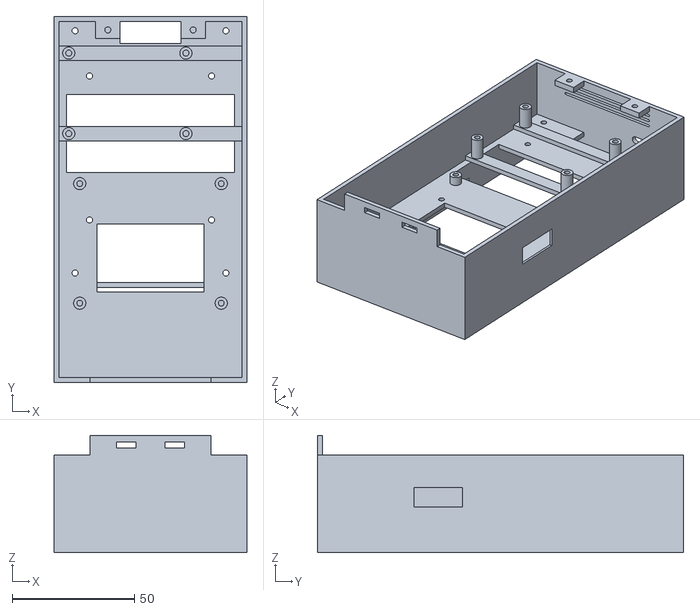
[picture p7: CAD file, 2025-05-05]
docs/models/BlackberryPi_Case_V4_TEMPORARY-Main_Case.stl
79.0 x 150.0 x 48.0

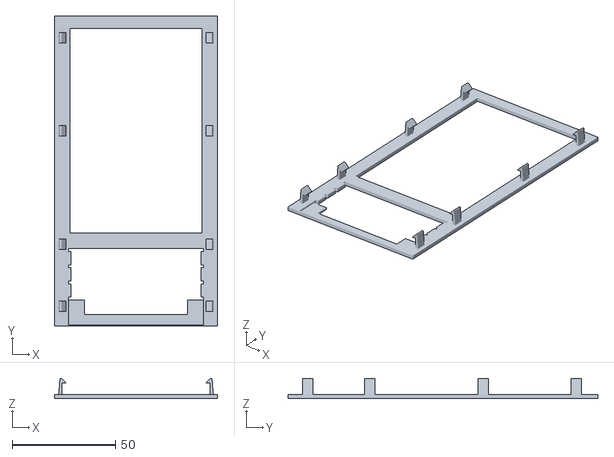
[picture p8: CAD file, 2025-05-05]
docs/models/BlackberryPi_Case_V4_TEMPORARY-Front_Panel.stl
79.0 x 150.0 x 9.90

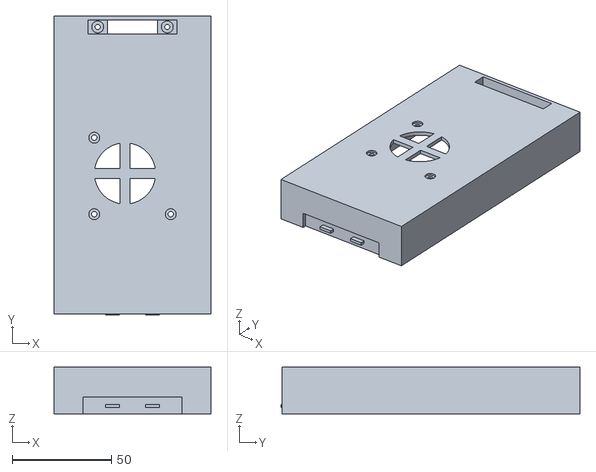
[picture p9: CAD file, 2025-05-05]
docs/models/BlackberryPi_Case_V4_TEMPORARY-Back_Panel.stl
79.0 x 150.5 x 23.5

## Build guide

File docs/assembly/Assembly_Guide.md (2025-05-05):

# BlackberryPi Assembly Guide

## Table of Contents
1. [Fastening Method](#1-fastening-method)
2. [Display and Keyboard Mounting](#2-display-and-keyboard-mounting)
3. [Electronics](#3-electronics)
4. [Wiring or Cables](#4-wiring-or-cables)
5. [Assembly Tools Required](#5-assembly-tools-required)
6. [Keyboard Setup](#6-keyboard-setup)
7. [Images and Diagrams](#7-images-and-diagrams)

---

## 1. Fastening Method

- The device is built around a main center piece.
- **Front Piece**:
  - Contains a slot for the keyboard and a display cutout to hide the edges.
  - Attached using 8 clips that snap into place when pressed into the main part.
- **Backplate**:
  - Slides into 2 slots at the bottom (similar to a battery case).
  - Secured with 2 screws at the top.

> 🔩 Total screws: **17**  
> Each screw hole is approximately **2.5 mm** in diameter.

---

## 2. Display and Keyboard Mounting

- **Display**:
  - Mounted inside a dedicated slot in the main piece.
  - Secured with 4 screws from the back (one per corner).
- **Keyboard**:
  - A Blackberry Q10 keyboard.
  - Press-fit into a custom slot in the front piece.
  - Fit may vary depending on 3D printer tolerances.

---

## 3. Electronics

- Core component: **Compute Module 5 (CM5)**
- Other components:
  - **Fan**: Mounted to backplate with 3 screws.
  - **Power Management HAT**: Secured to the main case with 4 screws.
  - **Battery**: Positioned to sit freely; no straps or mounts needed.

---

## 4. Wiring or Cables

- Care is required when:
  - Attaching the display ribbon cable.
  - Connecting all necessary GPIO pins for the Power Management HAT.
  - Hooking up the Blackberry keyboard wiring.

---

## 5. Assembly Tools Required

- **3D Printer** for printing the enclosure parts.
- **Screwdrivers** suitable for 2.5 mm screws.

---

## 6. Keyboard Setup

This project uses a **Blackberry Q10** keyboard, configured using the **Fairberry** guide.

➡️ Please follow the setup guide here:  
[Fairberry GitHub Repository](https://github.com/Dakkaron/Fairberry)

This step is essential for the keyboard to function properly.

---

## 7. Images and Diagrams

Images to be added:

- Component Diagram
- Explloded View

---

© PetabyteBrain – All rights reserved.

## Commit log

2025-04-23 bild und sonst änderungen zu realisierung
2025-05-05 Added Logo & 3d Models
    [BlackberryPi_Case_V4_TEMPORARY-Back_Panel.stl, BlackberryPi_Case_V4_TEMPORARY-Front_Panel.stl, BlackberryPi_Case_V4_TEMPORARY-Main_Case.stl]
